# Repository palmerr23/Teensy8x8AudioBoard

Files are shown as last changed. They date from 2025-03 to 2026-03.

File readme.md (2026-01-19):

# Teensy Audio TLV320AIC3104 8x8 CODEC Board 

### Discussions have been enabled for queries or suggestions about this hardware and software. 

The Board comprises four TLV320AIC3104 stereo CODECs and a PCA9546 I2C multiplexer to allow individual CODECs to be programmed. Audio data transfer is via TDM using the standard Teensy 4.x pin allocations. Pin 22 is used for reset.

These CODECs can be programmed to offset their read/write slots to anywhere in a 256 slot TDM cycle and put the DO line in a Hi-Z state when not transmitting.

The boards are stackable to provide additional channels, by using the three address pins on the I2C muxes for board selection. While up to eight boards can be stacked, the supplied TDMA driver can accommodate two boards. 

The associated Teensy audio control software library is at https://github.com/palmerr23/control_TLV320AIC3104

If more are desired, alternate Audio libraries, such as that managed by Jonathan Oakley https://github.com/h4yn0nnym0u5e/Audio/tree/feature/multi-TDM, are suggested.

# Hardware

There are several boards in the set. 

There is further hardware information in the "8x8 and 16x16 Teensy Audio Board.docx" file.

## Main PCB

The main PCB which has the four CODECs and control logic. It features:

* 8 input channels capable of microphone  to line level  balanced (-54 dBm to +10 dBm) or unbalanced (-60 dBm to -1.5 dBm) inputs.

* 8 balanced line output channels with a maximum output level of +10dBm (+4 dbm single-ended) and capable of driving headphones or 600 ohm lines.
	
* A multiplexer to allow I2C programming of individual CODECs. 
	
* An optional -5V supply (rear of PCB) for the amplified TRS wing board option.

* The main PCB does not have decoupling capacitors on the inputs or outputs. They are on the Wing boards.

* Rev K, L and M boards are entirely interoperable. 

* Rev L & M have an additional pin on the Expansion header to assist in 32 x 32 and greater operation.

## Input and output Wing boards
Wing-boards with input or output connectors and DC coupling capacitors. Several different wing boards are offered:
* 4 x 6.5mm balanced-line TRS phone jacks. These are suitable for inputs or outputs.  2 x 3.5mm stereo headphone sockets are also provided for the output configuration.
* Combo XLR/TRS sockets for balanced or unbalanced inputs.
* Male or Female XLR sockets for balanced input or outputs.
* Female XLR sockets with phantom powering - the user needs to provide a suitable phantom power voltage source.
* An amplified 4-channel TRS output board.

# Obtaining the hardware
Several options are available for obtaining hardware. 
* Download the [Gerber Files] and have boards produced by your favorite PCB manufacturer and then mount the SMD components. The CODEC chips gave QFN SMD (no pins) packages. Only experienced constructors should consider this option.
* For the main 8x8 boards, the repository has all the necessary files to order assembled (PCBA) boards from JLCPCB. These boards are supplied with just the SMD components. The headers required must be supplied and mounted by the constructor. Carefully check component orientation using the JLCPCB utility. The AMS117 regulators, the clock signal buffers under the Teensy and the I2C bus expander are sometimes rotated.
* Input and output coupling capacitors are not implemented on the PCB, so your implementation must include them if the Wing boards are not used.
* Purchase ready-made boards from my Tindie store https://www.tindie.com/products/palmerr223/teensy-8x8-audio-board/. 

## Compatibility
Arduino 4.x with Teensyduino 1.59 or later and the supplied TDMA driver.

## CPU Load

CPU load for the basic TDM transfers is low. 

* 16 output channels driven by a single sine generator, and no inputs processed consumes 0.12% CPU on a T4.0

* Adding 2 channels of peak readings increases it to 0.35%.

* 8 channels = 0.66%

* 16 channels = 1.1%

## Power consumption
With a Teensy 4.0 and one board and all input and output channels on all four CODECs enabled the consumption is around 130 mA, mostly consumed on the 1.8V rail.

On a T4.0 with two boards and everything enabled, consumption rises to around 220 mA.

These figures are without any significant load on the outputs. Current draw will increase with low impedance loads.

Chip data (p12) indicates 4.3 + 6.7 = 11 mA per stereo (input + output) channel pair (i.e. 88 mA for 8x8).

## Open Source Hardware
These designs are  certified Open Source Hardware

https://certification.oshwa.org/list.html

ID: AU000022

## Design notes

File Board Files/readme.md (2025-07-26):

## PCBA
When ordering assembled boards, carefully check parts orientation.

Particularly, the two AMS 1117 regulators, the ISC bus expander and the TDM clock buffer chips under the Teensy have a tendency to be rotated. 

## Connector templates
TRS Board - 1/4" TRS connector base height varies between manufacturers.

XLR & Combo mounting hole position and central cutout diameter varies between manufacturers.

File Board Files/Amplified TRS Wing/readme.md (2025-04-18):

# 4 output amplified TRS Wing Board for balanced or unbalanced outputs

This board requires +/-5V supplies (via the IDC cable).

It has a gain of 3, resulting in a maximum output level of 13.691k p-p (4.8V RMS) in balanced mode or 6.8V p-p (2.4V RMS) in single-ended mode

BOM file has indicative parts only.

*CPL files are not supplied as PCBA placement and parts have not been verified*

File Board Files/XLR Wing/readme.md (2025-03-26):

# Quad XLR input or output board for balanced or unbalanced signals

Male or Female XLR sockets. 

Male sockets (output) are mounted on the *underside* of the board to ensure correct signal phase.

Only one sockect of each type is shown for clarity.

BOM is indicative of parts required. It contains both Input and Output connectors - only one set is required.

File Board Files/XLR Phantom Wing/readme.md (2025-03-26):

# Quad XLR Phantom powered input board for balancedmicrophones

Female  XLR sockets. 

Imag shows only one sockect is shown for clarity.

BOM file is indicative of parts required in addition to the PCB.

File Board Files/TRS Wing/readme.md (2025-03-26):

# Quad 6.5mm balanced-line TRS phone jacks. 

These are suitable for inputs or outputs.  

2 x 3.5mm stereo headphone sockets are also provided for the *output* configuration.

Decoupling capacitors have different values for inputs (high-impedance) and outputs (low impedance) to ensure adequate bass response.

BOM file is indicative.

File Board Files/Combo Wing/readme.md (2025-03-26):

# 4 input Combo XLR/TRS Wing Board for balanced or unbalanced inputs

Only one Combo XLR socket is shown for clarity.

BOM file has indicative parts only.

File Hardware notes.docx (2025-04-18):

# 8x8 (16x16) Teensy Audio Board Technical Notes

V1.0 March 2025

These notes should be read as an adjunct to schematics and datasheets. They are indicative of design choices but do not guarantee functionality or performance.

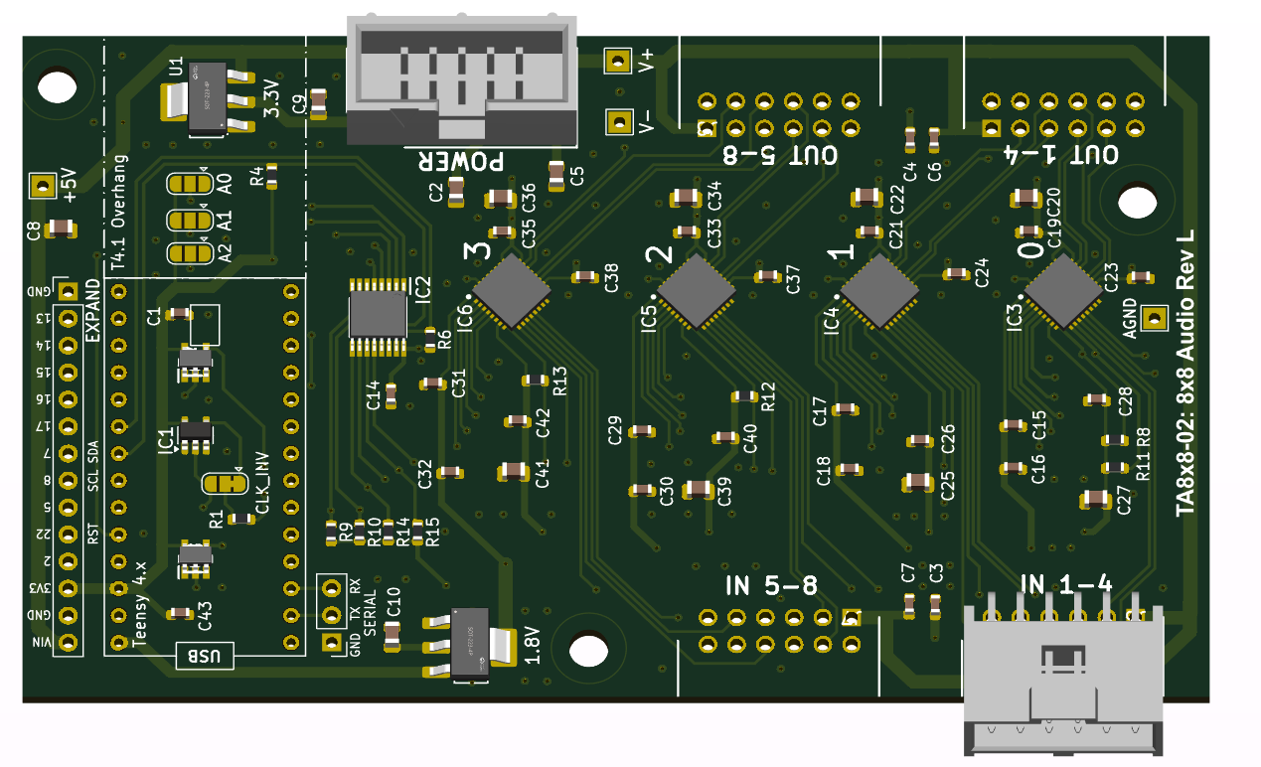
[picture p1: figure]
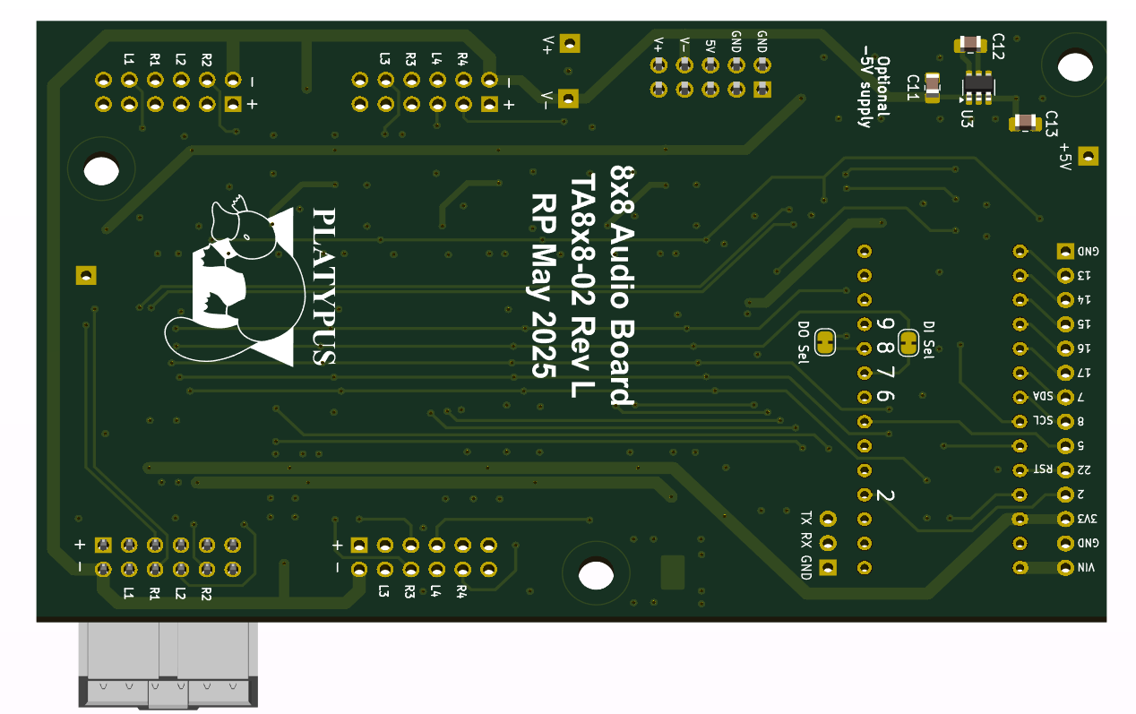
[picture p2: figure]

# Features

- 8x8 input and output channels
  - No input or output decoupling capacitors provided on main PCB.
    - Wing boards allow flexible mounting options for input and output connectors.
    - Wing boards have decoupling capacitors.
  - TLV320AIC3104 CODECs
    - TDM or I2S protocol
    - 16-, 24- or 32-bit samples
    - 44.1 or 48 kHz and multiples from 8 kHz to 96 kHz.
    - PLL capable when MCLK is absent.
- Two boards stackable (16x16) with standard Teensy TDM driver.
- Up to eight boards possible with advanced TDM drivers.
- Inputs
  - Balanced or single-ended.
  - Single-ended levels from 25 mVRMS (-60 dBm) to 0.71 VRMS (-1.5 dBm) using inbuilt PGAs.
  - Balanced levels from 50 mVRMS (-54 dBm) to 1.42 VRMS. (+10 dBm)
  - CODEC has inbuilt anti-aliasing filters on inputs and outputs.
- Outputs
  - 0.71 VRMS (2V p-p, +4 dBm) single ended or 1.42 VRMS (8V p-p, +10 dBm) differential.
  - Able to drive 16 Ω loads directly (30mW).
  - Amplified TRS wing board has x3 gain and can drive 600 Ω loads, but not low-impedance headphones.
- UART 1 is made available on a 3-pin header.
- Most unused pins are connected to a 14-pin expansion header, along with 3V, 3.3V power and the soft reset pin (22).
- A variety of input and output connector Wing boards
  - Designs are provided for 4-channel boards connected by 12-pin IDC cables.
  - All wing boards include electrolytic decoupling capacitors and anti-pop resistors.
    - ¼” TRS for input and output. Two 1/8” stereo headphone sockets are provided for the output configuration.
    - ¼” TRS amplified output. 2.4 VRMS (6.8V p-p) single ended or 4.8 VRMS (13.6V p-p) differential.
    - XLR input and output connectors.
    - Phantom powered XLR input.
    - Combo XLR input connectors.

# Specifications

Item | Measure
Output N+D (@ 90%) | 20-20kHz -92dB (differential)
Output Distortion (@ 90%) | 20-20kHz -93db 2nd Harmonic -98dB 3rd harmonic -95dB
Input N+D (Line: PGA gain = 0dB) | 20-20kHz -96dB (differential) THD (20-20k) 0.015%
Input N+D (Mic: PGA gain = 59 dB) | 20-20kHz -68dB (differential) THD (20-20k) 0.03%

### Input channel Noise and Distortion

Measured with REW @ 937 Hz at -2dB FSD.

Results show quite good performance up to 30dB gain and tapering off after that. Dynamic microphones (~50dB gain) may be better served with a low-noise preamp.

Gain | N+D (dB) | Distortion | ENOB
0dB | -97 | 0.007% | 16.0
20dB | -96 | 0.02% | 15.8
30dB | -89 | 0.02% | 14.9
40dB | -82 | 0.02% | 13.6
50dB | -75 | 0.03% | 12.0
59.5dB | -70 | 0.07% | 10.3

# Notes

- When a differential input signal is applied to a CODEC programmed as single-ended, some reflection will occur into the other channel. This appears to be because VCM is connected to the negative PGA input in single ended mode, providing a path between channels (Fig 10-13, p.36). To avoid this issue, program differential mode for all inputs for both single-ended and differential signals unless the CODECs negative input pins are not used (i.e. even pins on the input connector are left unconnected). All wing boards should be programmed with differential mode.
- When single-ended mode is used, all negative input signals should be left unconnected.

# Hardware

The hardware is compatible with Teensy 4.0 and 4.1. It may work with Teensy 3.x but this is untested.

### CODEC programming

The TLV320AIC3104 CODECs have a single I2C control address, requiring I2C multiplexing for programming multiple chips. A PCA9546A I2C mux provides access the individual TLV320AIC3104 CODEC control registers. The mux has eight addresses (0x70 – 0x77) available, selected by solder jumpers for A0-A2, providing a theoretical limit of eight boards (64 channels) attached to a single Teensy. In practice, the standard TDM driver limits the number of channels to 16.

I2C pull-up resistance is provided for each board (3.3k R8, R10) and the selected CODEC channel (6.8k) in parallel. R8/10 values are set so that the pull-up is adequate when no CODEC is selected and the current does not exceed the 3mA I2C limit when a CODEC is selected. The per-CODEC resistors are sufficient to pull-up SDA and SCL on an unselected CODEC.

If more than two boards are stacked, the value of R8/10 may need to be increased to limit the overall pull-up current to below 3mA. R8/10 = 6.8k is suggested, but not tested, for four boards.

The CODECs and mux are hard reset by a signal from GPIO 22.

### Multiple boards

The MCLK, LRCLK (WCLK) and BCLK signals have 47 Ω series resistors on each board to provide impedance matching and to damp line reflections. When more than two boards are stacked, these may need to be increased to 100 Ω per board.

0R jumpers are provided for the DI and DO signals to enable alternate Teensy pins to be used in advanced TDM modes. Series resistors may be required to condition these signals when more than two boards are stacked. They are not required for 8x8 or 16x16 operation.

### 32x32 channel operation

DI and DO need to be re-mapped on boards 3 &4. Further details are in the Commissioning Notes.

### Inputs and outputs

All CODEC inputs and outputs have on-chip filters, so further external filtering is not required.

Inputs have individually-settable PGAs with 0 – 59.5 dB gain and can be configured as differential or single-ended.

The higher-powered headphone (HP) output drivers are used as they can drive 16 Ω loads to a maximum of 30mW. Digital output level controls are not implemented as mixer and level control objects are provided in the Teensy Audio library and many objects that can output have level controls.

The line (LO) outputs are not made available at on-board connectors to save space and PCB complexity.

### Optional -5V supply

An optional LM2776 -5V voltage converter is provided on the rear of the PCB connected to the V- bus. It is intended to be powered from V+ which has been jumpered from VIN. The supply is rated at 200mA and is intended to power input or output circuitry, as required.

-5V supply components are NOT populated on the standard PCBA configuration.

### Power consumption

Each board consumes around 100mA with unloaded outputs and the ADCs and DACs of all four CODECs powered on. The majority of this is from the 1.8V rail.

3.3V consumption will rise significantly when driving low-impedance loads.

### Audio input and output connectors

Inputs and outputs are grouped in sets of four and can be configured as differential or single-ended.

The shrouded 12-pin input and output headers share pinouts to allow flexibility in the provision of appropriate audio connectors. The same connectors are used on all Wing boards and are intended to be connected via 12-way IDC cables.

The channel numbering on the inputs and outputs is different. Pin 3 is the first positive input pin, and the last positive output pin. The ground and power pins are the same on input and output connectors.

### Audio input and output connector pin-outs

Pin | Input | Output | | Pin | Input | Output
1 | V+ | V+ | | 2 | V- | V-
3 | IN1+ | OUT4+ | | 4 | IN1- | OUT4-
5 | IN2+ | OUT3+ | | 6 | IN2- | OUT3-
7 | IN3+ | OUT2+ | | 8 | IN3- | OUT2-
9 | IN4+ | OUT1+ | | 10 | IN4- | OUT1-
11 | AGND | AGND | | 12 | AGND | AGND

Connector types

Input and output (Main and Wing boards)
2 x 6 pin 2.54mm shrouded right-angle male IDC header

Right angle connectors are required if stacking several boards.

Power input
2 x 5 pin 2.54mm shrouded male IDC header

Only on the board with the Teensy

Mounting a long-pin female header on the underside of the PCB allows power pins to stack. This is only required if V+ and V- are used. The Teensy headers transfers 5V power.

Teensy and board interconnect

2 x single row 14 pin 2.54mm female header

Long pins if stacking boards.

Expansion

14 pins, including 5V, 3.3V power, ground and pin 22 reset.

Pinouts are marked on the underside of the PCB

### Expansion header

Signal | Rev K | Rev L onwards
| Pin
VIN | 14 | 15
GND | 13 | 14
3V3 | 12 | 13
2 | 11 | 12
22 RESET | 10 | 11
5 | 9 | 10
8 SCL | 8 | 9
7 SDA | 7 | 8
17 | 6 | 7
16 | 5 | 6
15 | 4 | 5
14 | 3 | 4
13 | 2 | 3
GND | 1 | 2
23 | | 1

GPIO Pins 2, 13,14,15 and 16 are uncommitted on the Expansion header.

The I2C bus and soft Reset signal are extended on the Expansion header as well as the Teensy header for boards.

An additional pin was added in Rev L to allow 32x32 operation. Other than that additional pin, the Expansion headers are compatible between revisions.

## Wing Boards

All wing boards, other than the amplified TRS board, are designed for through-hole components.

- 10uF or 100uF capacitors are 6.3 x 2.5mm, 10V or greater.
- 1uF capacitors are 5 x 2.5 mm, 10V or greater.
- Resistors are metal film, 1%, ¼ Watt.

All wing boards may be used in single-ended or differential mode. When used in single-ended mode, the coupling capacitors for the negative inputs should be omitted (see Fig 10-13 p.36) to allow these signals to float.

The 22 Ω or 47 Ω series resistors limit the output current when an active signal is grounded, for instance on TRS output boards that may single-ended cables (i.e., ring is grounded).

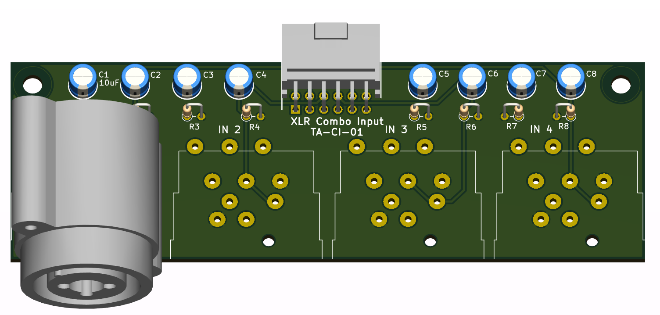
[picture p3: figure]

### Combo

This input board has four XLR combo connectors (Neutrik NCJ6FI-H, NCJ9FI-H or REAN equivalents) with decoupling capacitors and discharge resistors to reduce pops when hot-plugging.

### XLR

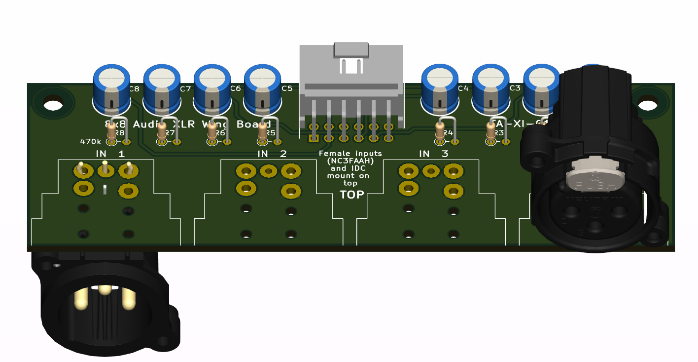
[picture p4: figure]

The XLR board has four connectors – female for inputs (Neutrik NC3FAAH or equivalent, mounted on the top of the PCB) or male for outputs (NC3MAAH or equivalent, mounted on the underside of the PCB.)

The IDC header is always mounted on the top of the board.

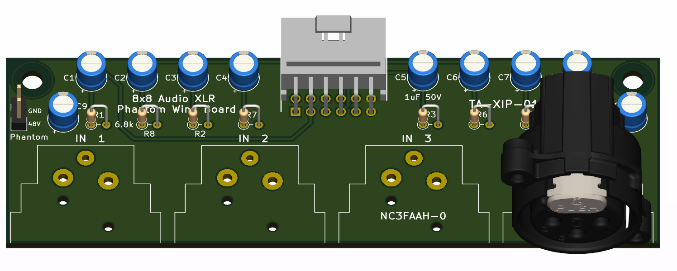
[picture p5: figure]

The board has decoupling capacitors and discharge resistors to reduce pops when hot-plugging.

### XLR Phantom input

The phantom-powered XLR input board has four female connectors (Neutrik NC3FAAH or equivalent).

A 2-pin header is provided for an external phantom power source. 6.8k phantom power resistors are specified for 48V operation. The values may be reduced for lower voltages.

The board has 50V decoupling capacitors.

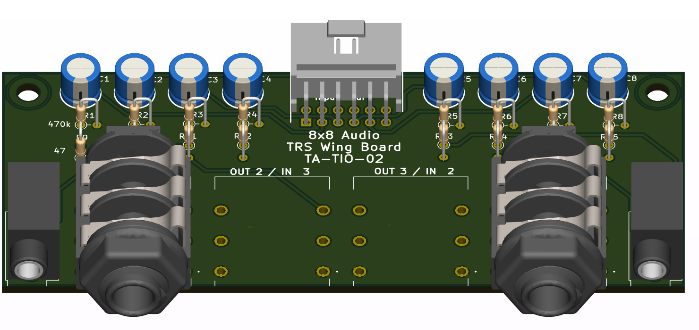
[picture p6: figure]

### TRS

The TRS board hosts four inputs or outputs.

The board has decoupling capacitors and discharge resistors to reduce pops when hot-plugging.

For output boards the 47 Ω current-limiting resistors R1-R8 are required to protect against single-ended (ring shorted to ground) cables.

For input boards the current-limiting resistors R1-R8 may be omitted and the pads linked.

The Amphenol (https://au.mouser.com/manufacturer/amphenolaudio/) ACJM-IH (https://au.mouser.com/ProductDetail/Amphenol-Audio/ACJM-IH?qs=t8VhaDIDl4v4EBLCsB4y7Q%3D%3D), Neutrik (https://au.mouser.com/manufacturer/neutrik/) NMJ4HFD3 (https://au.mouser.com/ProductDetail/Neutrik/NMJ4HFD3?qs=%252B86TLfaev2%252B4Sd%2FGmMLlUg%3D%3D) or compatible switched TRS connectors are mounted on the top of the board for both input and output applications.

Note that the channel order is different for input and output use.

If grounding of unused input channels is desired, jumpers on the underside of the PCB may be shorted. The jumpers MUST be left open for output boards.

1/8” (CUI SJ1-353xNG) headphone sockets are provided in parallel to the ¼” TRS sockets. The current-limiting resistors are bypassed. These are only required for the output configuration.

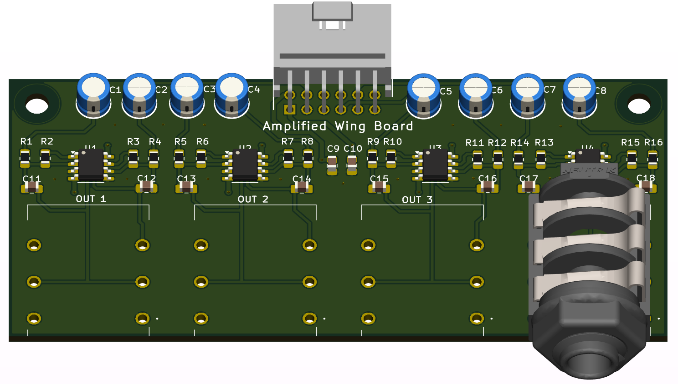
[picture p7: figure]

### Amplified TRS

Where higher-level outputs are required for professional applications the Amplified TRS board provides an additional 3x gain. The maximum levels are 2.4 VRMS (6.8V p-p) single ended and 4.8 VRMS
(13.6V p-p) differential. The board will drive 600 Ω lines to +24dBm, but is not recommended for low impedance headphones.

SMD components are used on this board to allow a more compact layout.

The LM2776 voltage inverter should be installed on the Teensy main board and Vin linked to V+. Alternately, suitable V+ and V- supplies may be provided via the Power connector.

If V+ and V- are greater than 5V, the gain may be increased to suit the op amps’ maximum output swing and drive capability. The maximum supply voltage of the op amps needs to be

# Teensy Audio Library AudioControl object

### AudioControl object

The driver for the I2C mux is incorporated into the control object and is invisible to end-user code.

The CODECs are set to select a specific 16-bit TDM slot (Reg 10) and tristate their outputs when not transmitting (Reg 8).

BCLK is inverted in hardware to avoid modifying the standard TDM driver further. This requires 1 bit to be added to the TDM slot delay.

On start-up the mux address range is scanned and 4-CODEC sets are assigned channel numbers in order of increasing mux address.

A verbose mode is available, with several levels of verbosity, for debugging.

The core functions have been tested substantially:

- 16-bit, 44.1 kHz, 8x8 and 16x16 TDM using the TDMA driver supplied.
- PGA gain using float dB or CODEC integer steps.
- 10, 20 & 50Hz high pass filters (zero offset removal).
- Single-ended and differential inputs.
- Standard “Wire” I2C at 100kHz and 400kHz.

Several other functions have been included that have only had basic checks:

- I2S operation.
- PLL to replace absent MCLK.
- 24 and 32 bit sample lengths.

Implemented and untested:

- TDMA and I2S input and output objects with sample lengths other than 16-bits.
- Sample rates other than 44.1 kHz and double rate operation.

CODEC capabilities not implemented:

- AGC
- Digital effects filtering
- Output level control (always set to 1.0). Duplicates existing Audio Library functions.
- ADC bypass functions
- Alternate mic-line inputs and MICBIAS.

## TDM driver

The standard Teensy Audio TDM driver (1.59) does not transfer odd channel audio buffers correctly. The TDMA driver supplied with the control object corrects this issue.

While the TDMA driver has an optional sample length argument, specifying 16-bits in the constructors is not required, as the default (32-bit) works with this hardware.

Jonathan Oakley’s Multi-TDM driver should also work with this hardware. https://github.com/h4yn0nnym0u5e/Audio/tree/feature/multi-TDM

(https://github.com/h4yn0nnym0u5e/Audio/tree/feature/multi-TDM)The multi-TDM driver is required if more than two boards are stacked.

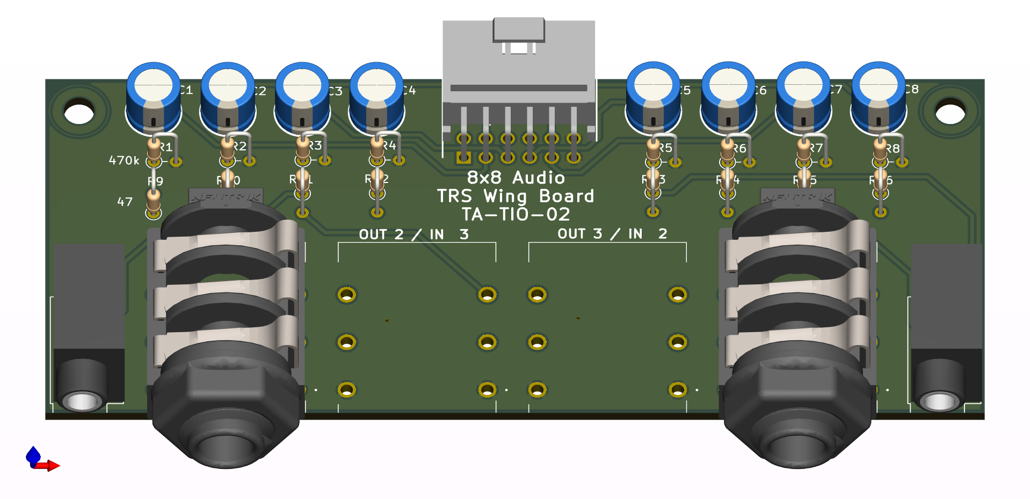
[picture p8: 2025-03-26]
Board Files/TRS Wing/Wing Board 4 TRS Mk IV.png

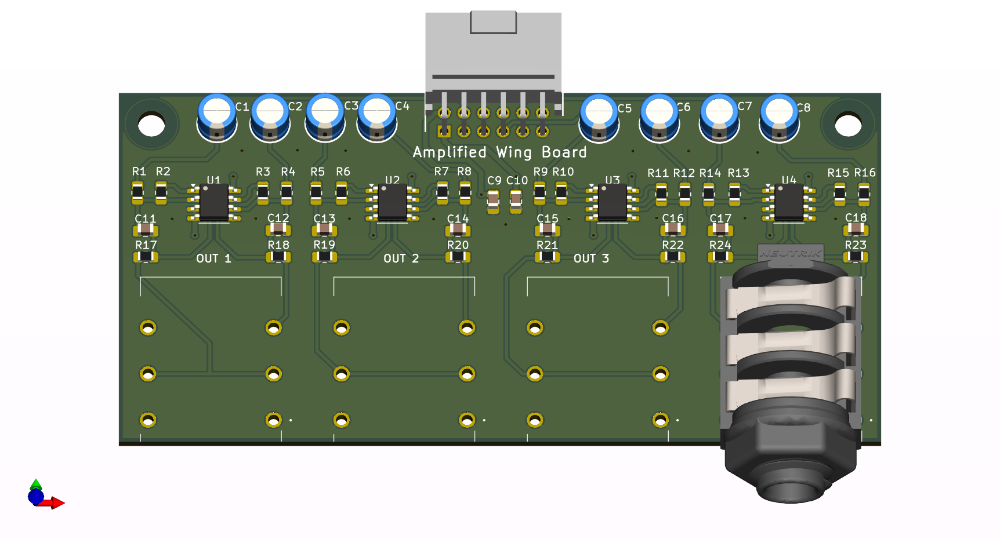
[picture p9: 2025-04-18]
Board Files/Amplified TRS Wing/Wing Board 4 TRS amp Mk II.png

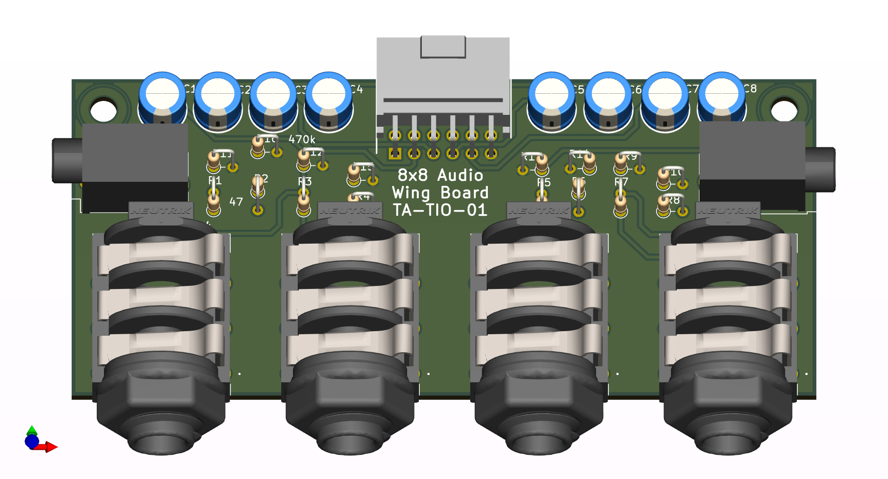
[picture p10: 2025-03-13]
Board Files/TRS Wing/Wing Board 4 TRS Mk III.png

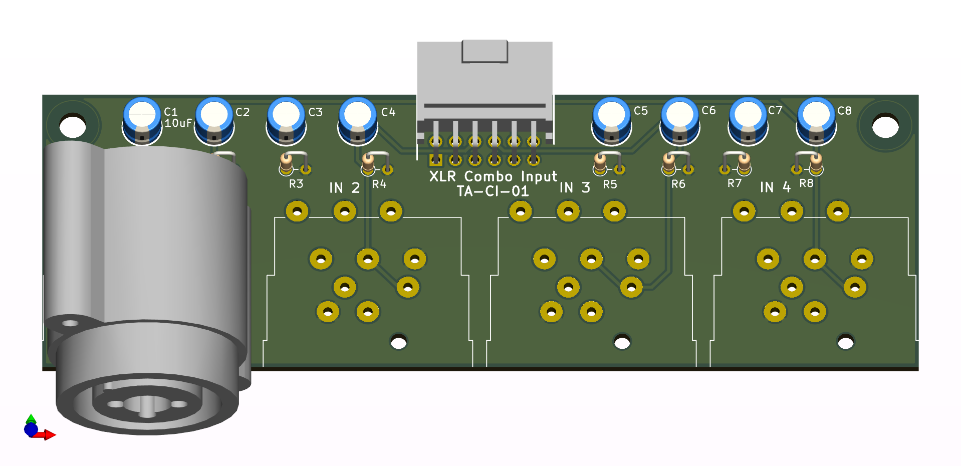
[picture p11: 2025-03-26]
Board Files/Combo Wing/Wing Board Combo.png

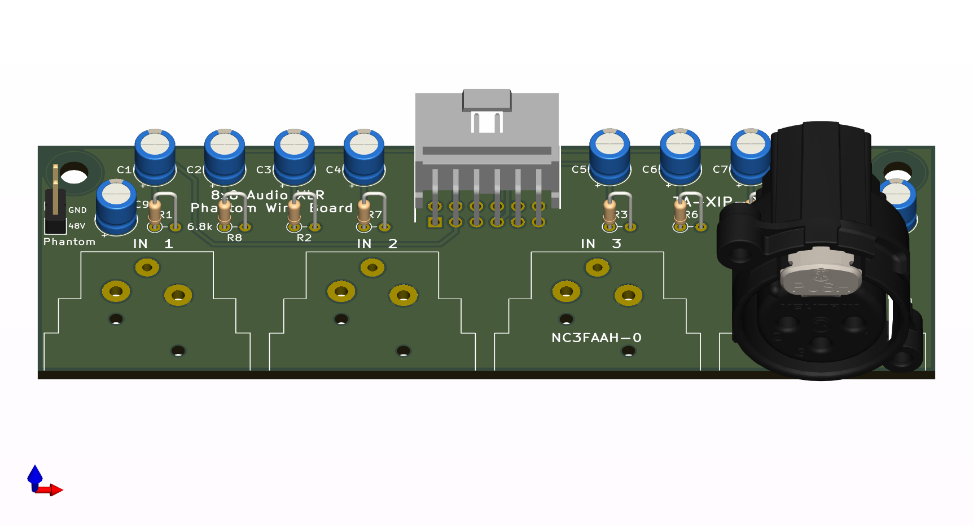
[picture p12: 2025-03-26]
Board Files/XLR Phantom Wing/Wing Board XLR Phantom.png

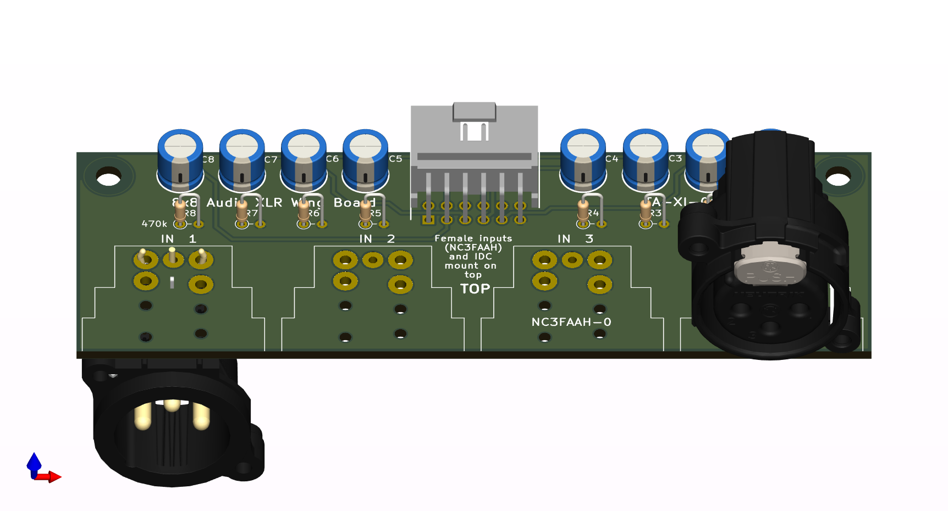
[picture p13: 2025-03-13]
Board Files/XLR Phantom Wing/Input Output XLR Wing Board.png

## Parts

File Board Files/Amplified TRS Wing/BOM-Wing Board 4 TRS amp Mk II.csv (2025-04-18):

Comment | Designator | Footprint | LCSC | Quantity
1u | C6 | CP_Radial_D5.0mm_P2.50mm |  | 1
NMJ6HFD2 | J4 | NMJ6HFD2 |  | 1
100k | R3 | R_0805_2012Metric_Pad1.20x1.40mm_HandSolder |  | 1
330p | C17 | C_0805_2012Metric_Pad1.18x1.45mm_HandSolder |  | 1
22k | R1 | R_0805_2012Metric_Pad1.20x1.40mm_HandSolder |  | 1
100k | R13 | R_0805_2012Metric_Pad1.20x1.40mm_HandSolder |  | 1
1u | C5 | CP_Radial_D5.0mm_P2.50mm |  | 1
100k | R2 | R_0805_2012Metric_Pad1.20x1.40mm_HandSolder |  | 1
330p | C15 | C_0805_2012Metric_Pad1.18x1.45mm_HandSolder |  | 1
330p | C14 | C_0805_2012Metric_Pad1.18x1.45mm_HandSolder |  | 1
100k | R15 | R_0805_2012Metric_Pad1.20x1.40mm_HandSolder |  | 1
22k | R8 | R_0805_2012Metric_Pad1.20x1.40mm_HandSolder |  | 1
330p | C16 | C_0805_2012Metric_Pad1.18x1.45mm_HandSolder |  | 1
1u | C8 | CP_Radial_D5.0mm_P2.50mm |  | 1
LM4562 | U3 | SOIC-8_3.9x4.9mm_P1.27mm |  | 1
100k | R7 | R_0805_2012Metric_Pad1.20x1.40mm_HandSolder |  | 1
Neutrik NMJ6HFD2 | J5 | NMJ6HFD2 |  | 1
LM4562 | U4 | SOIC-8_3.9x4.9mm_P1.27mm |  | 1
10u | C10 | C_0805_2012Metric_Pad1.18x1.45mm_HandSolder |  | 1
22k | R16 | R_0805_2012Metric_Pad1.20x1.40mm_HandSolder |  | 1
100k | R6 | R_0805_2012Metric_Pad1.20x1.40mm_HandSolder |  | 1
1u | C4 | CP_Radial_D5.0mm_P2.50mm |  | 1
1u | C3 | CP_Radial_D5.0mm_P2.50mm |  | 1
22k | R5 | R_0805_2012Metric_Pad1.20x1.40mm_HandSolder |  | 1
330p | C11 | C_0805_2012Metric_Pad1.18x1.45mm_HandSolder |  | 1
100k | R11 | R_0805_2012Metric_Pad1.20x1.40mm_HandSolder |  | 1
NMJ6HFD2 | J3 | NMJ6HFD2 |  | 1
INPUTS | J1 | SHDRRA12W65P254_2X6_1758X1090X1005P |  | 1
1u | C7 | CP_Radial_D5.0mm_P2.50mm |  | 1
10u | C9 | C_0805_2012Metric_Pad1.18x1.45mm_HandSolder |  | 1
330p | C18 | C_0805_2012Metric_Pad1.18x1.45mm_HandSolder |  | 1
22k | R14 | R_0805_2012Metric_Pad1.20x1.40mm_HandSolder |  | 1
330p | C12 | C_0805_2012Metric_Pad1.18x1.45mm_HandSolder |  | 1
NMJ6HFD2 | J2 | NMJ6HFD2 |  | 1
22k | R12 | R_0805_2012Metric_Pad1.20x1.40mm_HandSolder |  | 1
LM4562 | U2 | SOIC-8_3.9x4.9mm_P1.27mm |  | 1
LM4562 | U1 | SOIC-8_3.9x4.9mm_P1.27mm |  | 1
330p | C13 | C_0805_2012Metric_Pad1.18x1.45mm_HandSolder |  | 1
100k | R10 | R_0805_2012Metric_Pad1.20x1.40mm_HandSolder |  | 1
22k | R9 | R_0805_2012Metric_Pad1.20x1.40mm_HandSolder |  | 1
22k | R4 | R_0805_2012Metric_Pad1.20x1.40mm_HandSolder |  | 1
1u | C2 | CP_Radial_D5.0mm_P2.50mm |  | 1
1u | C1 | CP_Radial_D5.0mm_P2.50mm |  | 1
22 | R24 | R_0805_2012Metric_Pad1.20x1.40mm_HandSolder |  | 1
22 | R23 | R_0805_2012Metric_Pad1.20x1.40mm_HandSolder |  | 1
22 | R22 | R_0805_2012Metric_Pad1.20x1.40mm_HandSolder |  | 1
22 | R21 | R_0805_2012Metric_Pad1.20x1.40mm_HandSolder |  | 1
22 | R20 | R_0805_2012Metric_Pad1.20x1.40mm_HandSolder |  | 1
22 | R19 | R_0805_2012Metric_Pad1.20x1.40mm_HandSolder |  | 1
22 | R18 | R_0805_2012Metric_Pad1.20x1.40mm_HandSolder |  | 1
22 | R17 | R_0805_2012Metric_Pad1.20x1.40mm_HandSolder |  | 1

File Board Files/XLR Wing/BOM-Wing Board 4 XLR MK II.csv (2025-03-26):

Comment | Designator | Footprint | LCSC | Quantity
470k | R6 | R_Axial_DIN0204_L3.6mm_D1.6mm_P2.54mm_Vertical |  | 1
NC3FAAH-0 | J5 | Jack_XLR_Neutrik_NC3FAAH-0_Horizontal |  | 1
470k | R8 | R_Axial_DIN0204_L3.6mm_D1.6mm_P2.54mm_Vertical |  | 1
470k | R5 | R_Axial_DIN0204_L3.6mm_D1.6mm_P2.54mm_Vertical |  | 1
10uF | C8 | CP_Radial_D6.3mm_P2.50mm |  | 1
10uF | C5 | CP_Radial_D6.3mm_P2.50mm |  | 1
10uF | C7 | CP_Radial_D6.3mm_P2.50mm |  | 1
470k | R2 | R_Axial_DIN0204_L3.6mm_D1.6mm_P2.54mm_Vertical |  | 1
10uF | C3 | CP_Radial_D6.3mm_P2.50mm |  | 1
10uF | C6 | CP_Radial_D6.3mm_P2.50mm |  | 1
NC3FAAH-0 | J2 | Jack_XLR_Neutrik_NC3FAAH-0_Horizontal |  | 1
NC3FAAH-0 | J4 | Jack_XLR_Neutrik_NC3FAAH-0_Horizontal |  | 1
INPUTS | J1 | SHDRRA12W65P254_2X6_1758X1090X1005P |  | 1
470k | R4 | R_Axial_DIN0204_L3.6mm_D1.6mm_P2.54mm_Vertical |  | 1
470k | R1 | R_Axial_DIN0204_L3.6mm_D1.6mm_P2.54mm_Vertical |  | 1
10uF | C2 | CP_Radial_D6.3mm_P2.50mm |  | 1
10uF | C4 | CP_Radial_D6.3mm_P2.50mm |  | 1
470k | R7 | R_Axial_DIN0204_L3.6mm_D1.6mm_P2.54mm_Vertical |  | 1
470k | R3 | R_Axial_DIN0204_L3.6mm_D1.6mm_P2.54mm_Vertical |  | 1
10uF | C1 | CP_Radial_D6.3mm_P2.50mm |  | 1
NC3FAAH-0 | J3 | Jack_XLR_Neutrik_NC3FAAH-0_Horizontal |  | 1
NC3MAAH-1 | J9 | Jack_XLR_Neutrik_NC3MAAH-1_Horizontal |  | 1
NC3MAAH-1 | J6 | Jack_XLR_Neutrik_NC3MAAH-1_Horizontal |  | 1
NC3MAAH-1 | J8 | Jack_XLR_Neutrik_NC3MAAH-1_Horizontal |  | 1
NC3MAAH-1 | J7 | Jack_XLR_Neutrik_NC3MAAH-1_Horizontal |  | 1

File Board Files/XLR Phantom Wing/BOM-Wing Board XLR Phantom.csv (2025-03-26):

Comment | Designator | Footprint | LCSC | Quantity
1uF | C10 | CP_Radial_D5.0mm_P2.00mm |  | 1
1uF | C9 | CP_Radial_D5.0mm_P2.00mm |  | 1
Phantom | J5 | PinHeader_1x02_P2.54mm_Vertical |  | 1
1uF | C8 | CP_Radial_D5.0mm_P2.00mm |  | 1
1uF | C7 | CP_Radial_D5.0mm_P2.00mm |  | 1
1uF | C6 | CP_Radial_D5.0mm_P2.00mm |  | 1
1uF 50V | C5 | CP_Radial_D5.0mm_P2.00mm |  | 1
1uF | C4 | CP_Radial_D5.0mm_P2.00mm |  | 1
1uF | C3 | CP_Radial_D5.0mm_P2.00mm |  | 1
1uF | C2 | CP_Radial_D5.0mm_P2.00mm |  | 1
1uF | C1 | CP_Radial_D5.0mm_P2.00mm |  | 1
6.8k | R2 | R_Axial_DIN0204_L3.6mm_D1.6mm_P2.54mm_Vertical |  | 1
NC3FAAH-0 | J6 | Jack_XLR_Neutrik_NC3FAAH-0_Horizontal |  | 1
6.8k | R1 | R_Axial_DIN0204_L3.6mm_D1.6mm_P2.54mm_Vertical |  | 1
6.8k | R7 | R_Axial_DIN0204_L3.6mm_D1.6mm_P2.54mm_Vertical |  | 1
6.8k | R4 | R_Axial_DIN0204_L3.6mm_D1.6mm_P2.54mm_Vertical |  | 1
NC3FAAH-0 | J1 | Jack_XLR_Neutrik_NC3FAAH-0_Horizontal |  | 1
NC3FAAH-0 | J4 | Jack_XLR_Neutrik_NC3FAAH-0_Horizontal |  | 1
INPUTS | J3 | SHDRRA12W65P254_2X6_1758X1090X1005P |  | 1
6.8k | R3 | R_Axial_DIN0204_L3.6mm_D1.6mm_P2.54mm_Vertical |  | 1
6.8k | R5 | R_Axial_DIN0204_L3.6mm_D1.6mm_P2.54mm_Vertical |  | 1
6.8k | R8 | R_Axial_DIN0204_L3.6mm_D1.6mm_P2.54mm_Vertical |  | 1
6.8k | R6 | R_Axial_DIN0204_L3.6mm_D1.6mm_P2.54mm_Vertical |  | 1
NC3FAAH-0 | J2 | Jack_XLR_Neutrik_NC3FAAH-0_Horizontal |  | 1

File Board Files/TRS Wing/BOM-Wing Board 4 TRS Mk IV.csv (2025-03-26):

Comment | Designator | Footprint | LCSC | Quantity
10uF | C6 | CP_Radial_D6.3mm_P2.50mm |  | 1
NMJ6HFD2 | J4 | NMJ6HFD2 |  | 1
47 | R14 | R_Axial_DIN0204_L3.6mm_D1.6mm_P2.54mm_Vertical |  | 1
470k | R4 | R_Axial_DIN0204_L3.6mm_D1.6mm_P2.54mm_Vertical |  | 1
47 | R15 | R_Axial_DIN0204_L3.6mm_D1.6mm_P2.54mm_Vertical |  | 1
10uF | C5 | CP_Radial_D6.3mm_P2.50mm |  | 1
NMJ6HFD2 | J5 | NMJ6HFD2 |  | 1
47 | R9 | R_Axial_DIN0204_L3.6mm_D1.6mm_P2.54mm_Vertical |  | 1
10uF | C7 | CP_Radial_D6.3mm_P2.50mm |  | 1
CUI SJ1-353xNG | J2 | Jack_3.5mm_CUI_SJ1-3535NG_Horizontal_CircularHoles |  | 1
470k | R8 | R_Axial_DIN0204_L3.6mm_D1.6mm_P2.54mm_Vertical |  | 1
470k | R3 | R_Axial_DIN0204_L3.6mm_D1.6mm_P2.54mm_Vertical |  | 1
47 | R13 | R_Axial_DIN0204_L3.6mm_D1.6mm_P2.54mm_Vertical |  | 1
10uF | C4 | CP_Radial_D6.3mm_P2.50mm |  | 1
10uF | C3 | CP_Radial_D6.3mm_P2.50mm |  | 1
470k | R1 | R_Axial_DIN0204_L3.6mm_D1.6mm_P2.54mm_Vertical |  | 1
47 | R11 | R_Axial_DIN0204_L3.6mm_D1.6mm_P2.54mm_Vertical |  | 1
Neutrik NMJ6HFD2 | J6 | NMJ6HFD2 |  | 1
INPUTS | J1 | SHDRRA12W65P254_2X6_1758X1090X1005P |  | 1
470k | R5 | R_Axial_DIN0204_L3.6mm_D1.6mm_P2.54mm_Vertical |  | 1
10uF | C8 | CP_Radial_D6.3mm_P2.50mm |  | 1
470k | R6 | R_Axial_DIN0204_L3.6mm_D1.6mm_P2.54mm_Vertical |  | 1
NMJ6HFD2 | J3 | NMJ6HFD2 |  | 1
CUI SJ1-353xNG | J7 | Jack_3.5mm_CUI_SJ1-3535NG_Horizontal_CircularHoles |  | 1
47 | R10 | R_Axial_DIN0204_L3.6mm_D1.6mm_P2.54mm_Vertical |  | 1
470k | R2 | R_Axial_DIN0204_L3.6mm_D1.6mm_P2.54mm_Vertical |  | 1
47 | R12 | R_Axial_DIN0204_L3.6mm_D1.6mm_P2.54mm_Vertical |  | 1
10uF | C2 | CP_Radial_D6.3mm_P2.50mm |  | 1
10uF | C1 | CP_Radial_D6.3mm_P2.50mm |  | 1
470k | R7 | R_Axial_DIN0204_L3.6mm_D1.6mm_P2.54mm_Vertical |  | 1
47 | R16 | R_Axial_DIN0204_L3.6mm_D1.6mm_P2.54mm_Vertical |  | 1
GND | JP7 | SolderJumper-2_P1.3mm_Open_RoundedPad1.0x1.5mm |  | 1
GND | JP4 | SolderJumper-2_P1.3mm_Open_RoundedPad1.0x1.5mm |  | 1
GND | JP6 | SolderJumper-2_P1.3mm_Open_RoundedPad1.0x1.5mm |  | 1
GND | JP8 | SolderJumper-2_P1.3mm_Open_RoundedPad1.0x1.5mm |  | 1
GND | JP2 | SolderJumper-2_P1.3mm_Open_RoundedPad1.0x1.5mm |  | 1
GND | JP1 | SolderJumper-2_P1.3mm_Open_RoundedPad1.0x1.5mm |  | 1
GND | JP3 | SolderJumper-2_P1.3mm_Open_RoundedPad1.0x1.5mm |  | 1
GND | JP5 | SolderJumper-2_P1.3mm_Open_RoundedPad1.0x1.5mm |  | 1

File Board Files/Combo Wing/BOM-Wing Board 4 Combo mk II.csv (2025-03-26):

Comment | Designator | Footprint | LCSC | Quantity
470k | R5 | R_Axial_DIN0204_L3.6mm_D1.6mm_P2.54mm_Vertical |  | 1
470k | R4 | R_Axial_DIN0204_L3.6mm_D1.6mm_P2.54mm_Vertical |  | 1
NCJ9FI-H | J5 | Jack_XLR-6.35mm_Neutrik_NCJ9FI-H_Horizontal |  | 1
10uF | C4 | CP_Radial_D5.0mm_P2.00mm |  | 1
470k | R2 | R_Axial_DIN0204_L3.6mm_D1.6mm_P2.54mm_Vertical |  | 1
NCJ9FI-H | J3 | Jack_XLR-6.35mm_Neutrik_NCJ9FI-H_Horizontal |  | 1
10uF | C8 | CP_Radial_D5.0mm_P2.00mm |  | 1
470k | R8 | R_Axial_DIN0204_L3.6mm_D1.6mm_P2.54mm_Vertical |  | 1
INPUTS | J1 | SHDRRA12W65P254_2X6_1758X1090X1005P |  | 1
470k | R7 | R_Axial_DIN0204_L3.6mm_D1.6mm_P2.54mm_Vertical |  | 1
470k | R1 | R_Axial_DIN0204_L3.6mm_D1.6mm_P2.54mm_Vertical |  | 1
NCJ9FI-H | J4 | Jack_XLR-6.35mm_Neutrik_NCJ9FI-H_Horizontal |  | 1
10uF | C3 | CP_Radial_D5.0mm_P2.00mm |  | 1
NCJ9FI-H | J2 | Jack_XLR-6.35mm_Neutrik_NCJ9FI-H_Horizontal |  | 1
10uF | C2 | CP_Radial_D5.0mm_P2.00mm |  | 1
10uF | C7 | CP_Radial_D5.0mm_P2.00mm |  | 1
470k | R3 | R_Axial_DIN0204_L3.6mm_D1.6mm_P2.54mm_Vertical |  | 1
470k | R6 | R_Axial_DIN0204_L3.6mm_D1.6mm_P2.54mm_Vertical |  | 1
10uF | C6 | CP_Radial_D5.0mm_P2.00mm |  | 1
10uF | C5 | CP_Radial_D5.0mm_P2.00mm |  | 1
10uF | C1 | CP_Radial_D5.0mm_P2.00mm |  | 1

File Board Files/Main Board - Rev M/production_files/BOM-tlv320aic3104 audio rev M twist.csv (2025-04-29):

Comment | Designator | Footprint | LCSC | Quantity
100n | C14,C15,C17,C19,C21,C26,C28,C29,C31,C33,C35,C40,C42 | C_0603 | C14663 | 13
1u | C1,C16,C18,C23,C24,C3,C30,C32,C37,C38,C4,C43,C6,C7 | C_0603 | C15849 | 14
10u | C10,C2,C20,C22,C25,C27,C34,C36,C39,C41,C5,C8,C9 | C_0805 | C15850 | 13
TLV320AIC3104IRHBR | IC3,IC4,IC5,IC6 | QFN50P500X500X100-33N-D | C181753 | 4
3k3 | R4,R6 | R_0603 | C22978 | 2
47 | R1,R2,R3 | R_0603 | C23182 | 3
6k8 | R10,R11,R12,R13,R14,R15,R8,R9 | R_0603 | C23212 | 8
SN74LVC1G125DBVR | IC7,IC8 | SOT95P280X145-5N | C23654 | 2
PCA9546APWR | IC2 | SOP65P640X120-16N | C400705 | 1
AMS1117-1.8 | U2 | SOT-223-3_L6.5-W3.4-P2.30-LS7.0-BR | C6185 | 1
AMS1117-3.3 | U1 | SOT-223-3_L6.5-W3.4-P2.30-LS7.0-BR | C6186 | 1
SN74LVC1G04DBVR-MS | IC1 | SOT-23-5 | C7434171 | 1

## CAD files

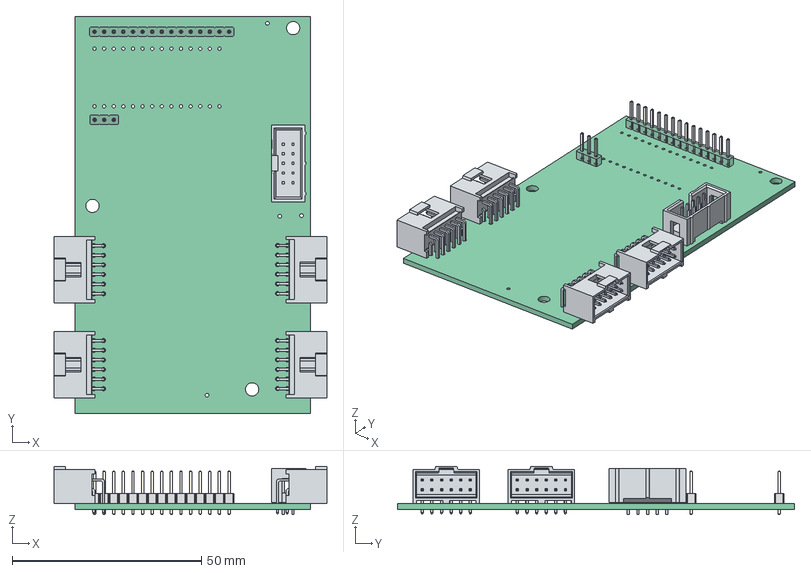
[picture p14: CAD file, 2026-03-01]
Board Files/Main Board - Rev M/tlv320aic3104 audio rev M twist.step
72.1 x 104.9 x 12.8 mm
Pcb_9f5c
J1_PinHeader_1x03_P254mm_Vertical_641d8b180097
POWER1_C-1761681-3_bb0363d08ec1
J4_901303112_a920b62f8c90 x 4
J2_PinHeader_1x15_P254mm_Vertical_3d8c39330363

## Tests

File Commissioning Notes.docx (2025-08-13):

# 8x8 Teensy Audio Board Commissioning Notes

V1.0 April 2025

These notes explain matters relevant to building and commissioning the main CODEC board and Wing boards.

There is relevant information in the Technical Notes that is not duplicated here.

Project schematics and component datasheets may also be valuable resources. Page references are to the TVL320AIC3104 datasheet.

# PCBA boards from JLCPCB

For the main 8x8 boards, the repository has all the necessary files to order assembled (PCBA) boards from JLCPCB. These boards are supplied with just the SMD components.

The headers required must be supplied and mounted by the constructor.

Carefully check component orientation using the JLCPCB utility. The AMS117 regulators, the clock signal buffers under the Teensy and the I2C bus expander are sometimes rotated.

# Stacking

12x3mm spacers should be used for stacking boards. The ones with 6mm male screw threads provide more secure mounting than those with 3mm threads.

Constructors should ensure that the 5V power supply is adequate.

If more than two boards are stacked or significant power is drawn on the V+ and V- lines (when connected to VIN and the on-board -5V supply), the POWER header should be used rather than the USB connector on the Teensy, as the current draw is likely to approach or exceed 0.5 amps.

Where the POWER connector is used, care should be taken to ensure correct orientation of the IDC cable (see Connectors, below).

Where the USB connector is used for an audio connection and +5V power is being supplied through the POWER connector, the instructions on the Teensy website for non-USB powering should be followed - https://www.pjrc.com/store/teensy40.html

## On-board jumpers

To function correctly each board in a stack must be jumpered to a different address.

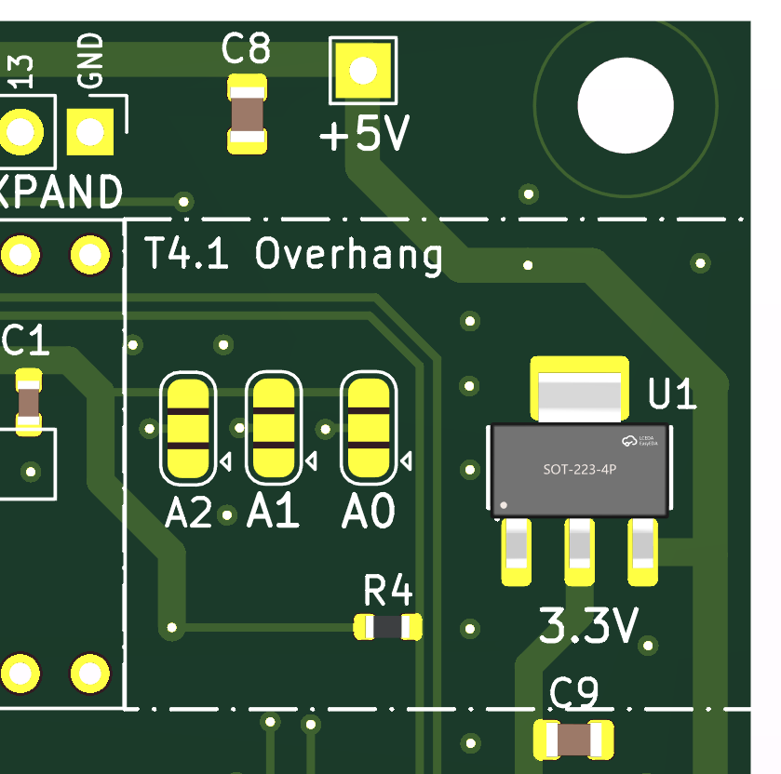
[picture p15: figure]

This is accomplished by bridging the appropriate pads on the A0 A1 and A2 jumpers near the end of the Teensy headers. The pair of pads near the Ax legends is 0 and the opposite pair is 1.

For the first board, the jumpers are:

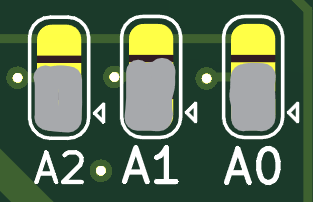
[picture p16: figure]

For the second board:

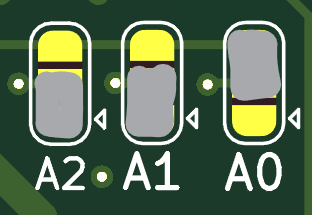
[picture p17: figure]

The input and output channel numbers are assigned using these addresses. The physical stacking order does not matter.

## 32x32 mode (Rev L or later ONLY)

Jonathan Oakley’s Multi-TDM driver is required if more than two boards are stacked. https://github.com/h4yn0nnym0u5e/Audio/tree/feature/multi-TDM

(https://github.com/h4yn0nnym0u5e/Audio/tree/feature/multi-TDM)On the main PCB (with the Teensy) GPIO pin 23 needs to be connected to the expansion header in 32x32 mode using a fly-lead.

The pin is at the end near the SD card holder on a T4.1 and on the rear of a T4.0

The DI and DO jumpers on the rear of boards 3 & 4 in the stack should be cut and connected:
to DI <–> Teensy GPIO 6 and DO <–> Teensy GPIO 23.

Board | DO GPIO | DI GPIO
1 & 2 | 8 | 7
3 & 4 | 6 | 23

# Input Configuration

When a differential input signal is applied to a CODEC programmed as single-ended, some reflection will occur into the other channel. This appears to be because VCM is connected to the negative PGA input in single ended mode, providing a path between channels (Fig 10-13, p.36).

To avoid this issue, program differential mode for all inputs for both single-ended and differential signals unless the CODECs negative input pins are not used (i.e. even pins on the input connector are left unconnected).

All wing boards should be programmed with differential mode.

When single-ended mode is used, all negative input signals should be left unconnected.

# Connectors

### Main Board

The four 6x2 right-angle IDC input and output connectors mount on the top of the PCB.

The 14-pin Teensy headers are supplied with long pins to enable stacking multiple boards. If stacking is not required, the pins may be trimmed after soldering.

The 5x2 power connector is a long-pin female type, which mounts on the REAR of the PCB to facilitate stacking. To protect against incorrect orientation of the IDC power cable the outer shell of a shrouded 5x2 male connector can be slipped over the pins. Some countersinking of the pin holes on the underside of the shell may be required for the shroud to fit snugly to the PCB.

For 8x8 configurations the POWER connector can be substituted with a 5x2 shrouded male IDC connector.

The EXPANSION header does not need to be connected between CODEC boards.

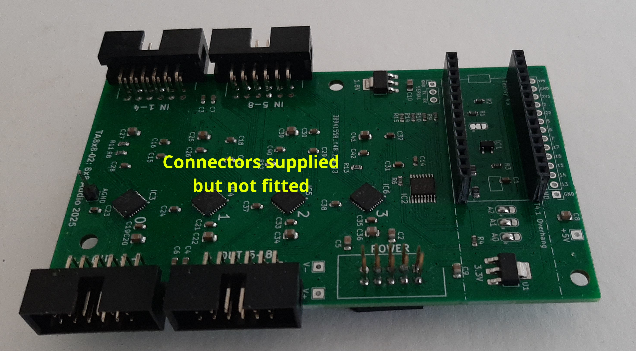
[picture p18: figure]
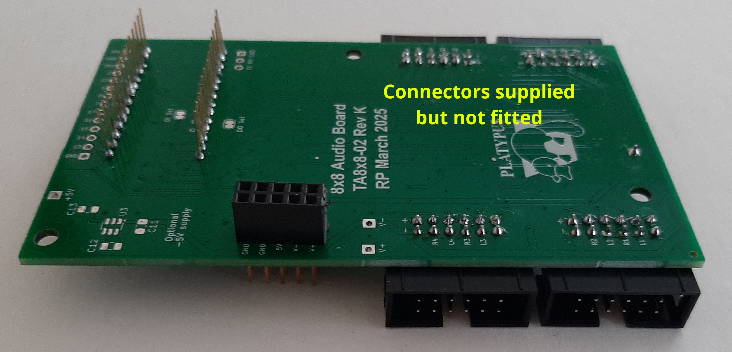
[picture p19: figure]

### Wing Boards

The IDC connector mounts on the top of the PCB for all Wing boards.

On the XLR Input/Output board:

- Input (female) connectors mount on the TOP of the board.
- Output (male) connectors mount on the BOTTOM of the board

On the TRS board:

- The 1/8” headphone jacks are only required for the output configuration.

The channel numbering on the 6x2 IDC connector for inputs and outputs is different. Pin 3 is the first positive input pin, and the last positive output pin. The ground and power pins are the same on input and output connectors.

### Input and Output Connectors (2 x6)

Pin | Input | Output | | Pin | Input | Output
1 | V+ | V+ | | 2 | V- | V-
3 | IN1+ | OUT4+ | | 4 | IN1- | OUT4-
5 | IN2+ | OUT3+ | | 6 | IN2- | OUT3-
7 | IN3+ | OUT2+ | | 8 | IN3- | OUT2-
9 | IN4+ | OUT1+ | | 10 | IN4- | OUT1-
11 | AGND | AGND | | 12 | AGND | AGND

### Power Connector (2x5)

Pin | Signal | | Pin | Signal
1 | GND | | 2 | GND
3 | GND | | 4 | GND
5 | VIN (+5V) | | 6 | VIN (+5V)
7 | V- (analogue) | | 8 | V-
9 | V+ (analogue | | 10 | V+

### Main Board Connector Types

Connectors

Input and output (Main and Wing boards)
2 x 6 pin 2.54mm shrouded right-angle male IDC header

Right angle connectors are required if stacking several boards.

Power input
Stacked: 2 x 5 pin 2.54mm long pin female header

Single board: 2 x 5 pin 2.54mm male shrouded IDC header

Mounting a long-pin female header on the underside of the PCB allows power pins to stack. This is only required if V+ and V- are used. The Teensy headers transfer 5V and 3.3V power.

Teensy and board interconnect

2 x single row 14 pin 2.54mm female header

Long pins if stacking boards.

Expansion

14 pins, including 5V, 3.3V power, ground and pin 22 reset.

Pinouts are marked on the underside of the PCB

The expansion header does not need to be connected between boards.

### Expansion header

Pin | Signal
14 | VIN
13 | GND
12 | 3V3
11 | 2
10 | 22 RST
9 | 5
8 | 8 SCL
7 | 7 SDA
6 | 17
5 | 16
4 | 15
3 | 14
2 | 13
1 | GND

GPIO Pins 2, 13,14,15 and 16 are uncommitted on the Expansion header.

The I2C bus and soft Reset signal are extended on the Expansion header as well as the Teensy header for boards.

## Wing Board Components

Electrolytic capacitors are polarity-sensitive. The white stripe on the capacitor matches with the white semicircle on the PCB. Resistors are not polarised.

All wing boards, other than the amplified TRS board, are designed for through-hole components.

The boards have decoupling capacitors and discharge resistors to reduce pops when hot-plugging.

1uF or 10uF electrolytic capacitors may be used for all inputs (the ADC input impedance is > 30 K ohms).

On outputs, 100uF capacitors provide better low frequency response when driving low-impedance loads such as headphones or 600 ohm balanced lines.

- 10uF or 100uF capacitors are 6.3 x 2.5mm, 10V or greater.
- 50V capacitors are required for phantom powering.
- 1uF capacitors are 5 x 2.5 mm, 10V or greater.
- Resistors are metal film, 5%, ¼ Watt.

All wing boards may be used in single-ended or differential mode. When used in single-ended mode, the coupling capacitors for the negative inputs should be omitted (see Fig 10-13 p.36) to allow these signals to float (see Input Configuration, below).

For output boards the 47 Ω current-limiting resistors R1-R8 are required to protect against single-ended (ring shorted to ground) cables.

### TRS

The TRS board hosts four inputs or outputs.

For input boards the current-limiting resistors R1-R8 may be omitted and the pads linked.

The Amphenol (https://au.mouser.com/manufacturer/amphenolaudio/) ACJM-IH (https://au.mouser.com/ProductDetail/Amphenol-Audio/ACJM-IH?qs=t8VhaDIDl4v4EBLCsB4y7Q%3D%3D), Neutrik (https://au.mouser.com/manufacturer/neutrik/) NMJ4HFD3 (https://au.mouser.com/ProductDetail/Neutrik/NMJ4HFD3?qs=%252B86TLfaev2%252B4Sd%2FGmMLlUg%3D%3D) or compatible switched TRS connectors are mounted on the top of the board for both input and output applications.

If grounding of unused input channels is desired, jumpers on the underside of the PCB may be shorted. The jumpers MUST be left open for output boards.

Note that the channel order is different for input and output use.

1/8” (CUI SJ1-353xNG) headphone sockets are provided in parallel to the ¼” TRS sockets. The current-limiting resistors are bypassed. These are only required for the output configuration.

### XLR

The XLR board has four connectors – female for inputs (Neutrik NC3FAAH or equivalent, mounted on the top of the PCB) or male for outputs (NC3MAAH or equivalent, mounted on the underside of the PCB.)

### Combo XLR

This input board has four XLR combo connectors (Neutrik NCJ6FI-H, NCJ9FI-H or REAN equivalents) with decoupling capacitors and discharge resistors to reduce pops when hot-plugging.

## Additional designs

### Amplified TRS

Where higher-level outputs are required for professional applications the Amplified TRS board provides an additional 3x gain. The maximum levels are 2.4 VRMS (6.8V p-p) single ended and 4.8 VRMS (13.6V p-p) differential. The board will drive 600 Ω lines to +8dBm, but is not recommended for low impedance headphones.

SMD components are used on this board to allow a more compact layout.

The LM2776 voltage inverter should be installed on the Teensy main board and Vin linked to V+. Alternately, suitable V+ and V- supplies may be provided via the Power connector.

If V+ and V- are greater than 5V, the gain may be increased to suit the op amps’ maximum output swing and drive capability. The maximum supply voltage of the op amps needs to be at least equal to the sum of the supply rail voltages.

### XLR Phantom input

The phantom-powered XLR input board has four female connectors (Neutrik NC3FAAH or equivalent).

A 2-pin header is provided for an external phantom power source. 6.8k phantom power resistors are specified for 48V operation. The values may be reduced for lower voltages.

The board has 50V decoupling capacitors.

# Using the Boards

## Software

The examples provided with the control_TLV320AIC3104 library demonstrate the basic requirements: of using the control_TLV320AIC3104 object to enable the CODECs and TDM transfers.

To simplify coding of multiple inputs and outputs, dynamic AudioConnections are demonstrated.

Function references are in the readme.md file provided with the library.

As of Teensyduino 1.59 the standard TDM driver does not handle samples from odd numbered channels correctly. The TDMA driver supplied with the library does. It is believed that 1.60 will correct the issues, but a release date had not been set at the time of writing.

Jonathan Oakley’s Multi-TDM driver should also work with this hardware. https://github.com/h4yn0nnym0u5e/Audio/tree/feature/multi-TDM

(https://github.com/h4yn0nnym0u5e/Audio/tree/feature/multi-TDM)The multi-TDM driver is required if more than two boards are stacked.

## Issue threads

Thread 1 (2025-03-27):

real-time multiple channel

shihweichieh2023, 2025-03-27:
Hi

Does this supports usb audio interface? so I can send multiple audio channels from my DAW in TDM in realtime?

palmerr23, 2025-03-27:
**Please use the teensy discussion forum for questions.**

Short answer. USB is separate and you can connect to it if you like. USB is 2 channels only due to Teensy USB speed. My Teensy Ethernet Audio can do multiple channels using a T4.1. Works with this board. You need to use the VBAN interface for your DAW.

palmerr23, 2025-03-27:
No I'm not interested. Thank you for the offer.

Closed 2025-03-27.

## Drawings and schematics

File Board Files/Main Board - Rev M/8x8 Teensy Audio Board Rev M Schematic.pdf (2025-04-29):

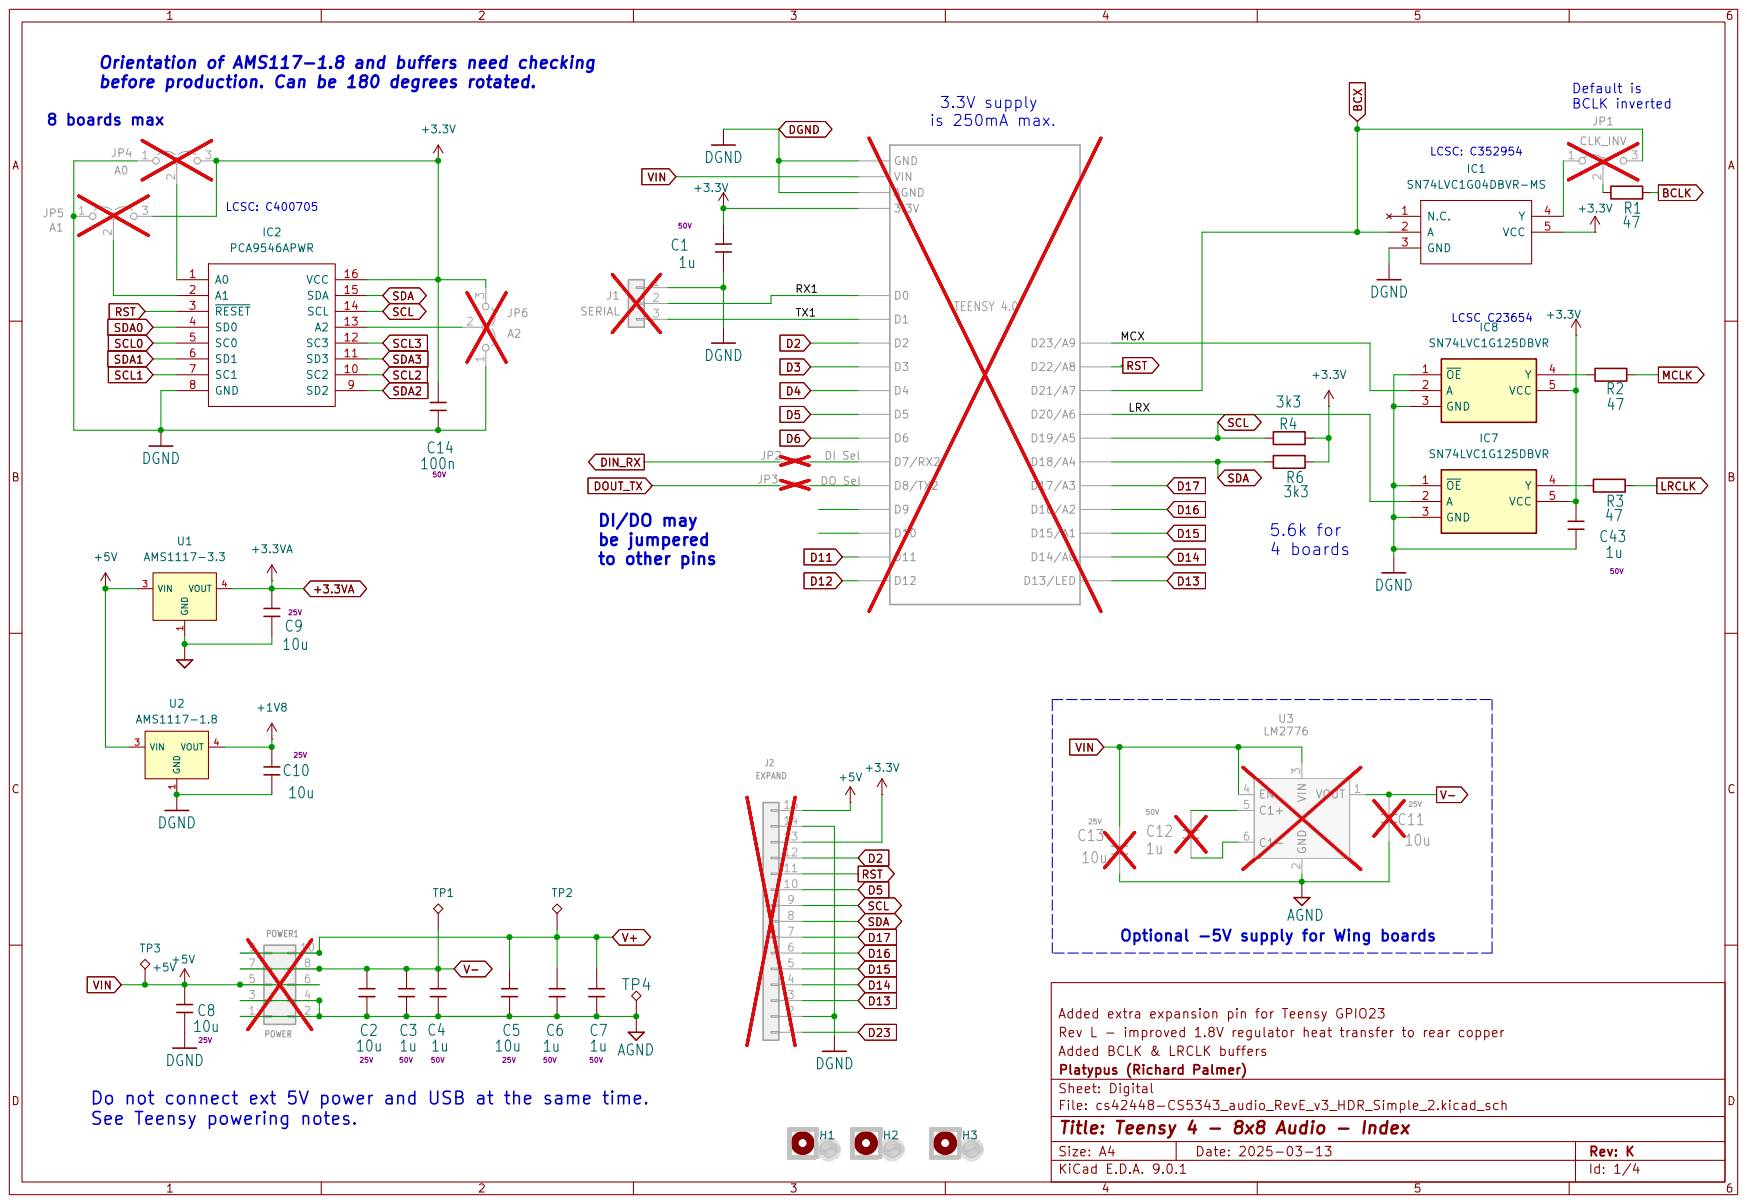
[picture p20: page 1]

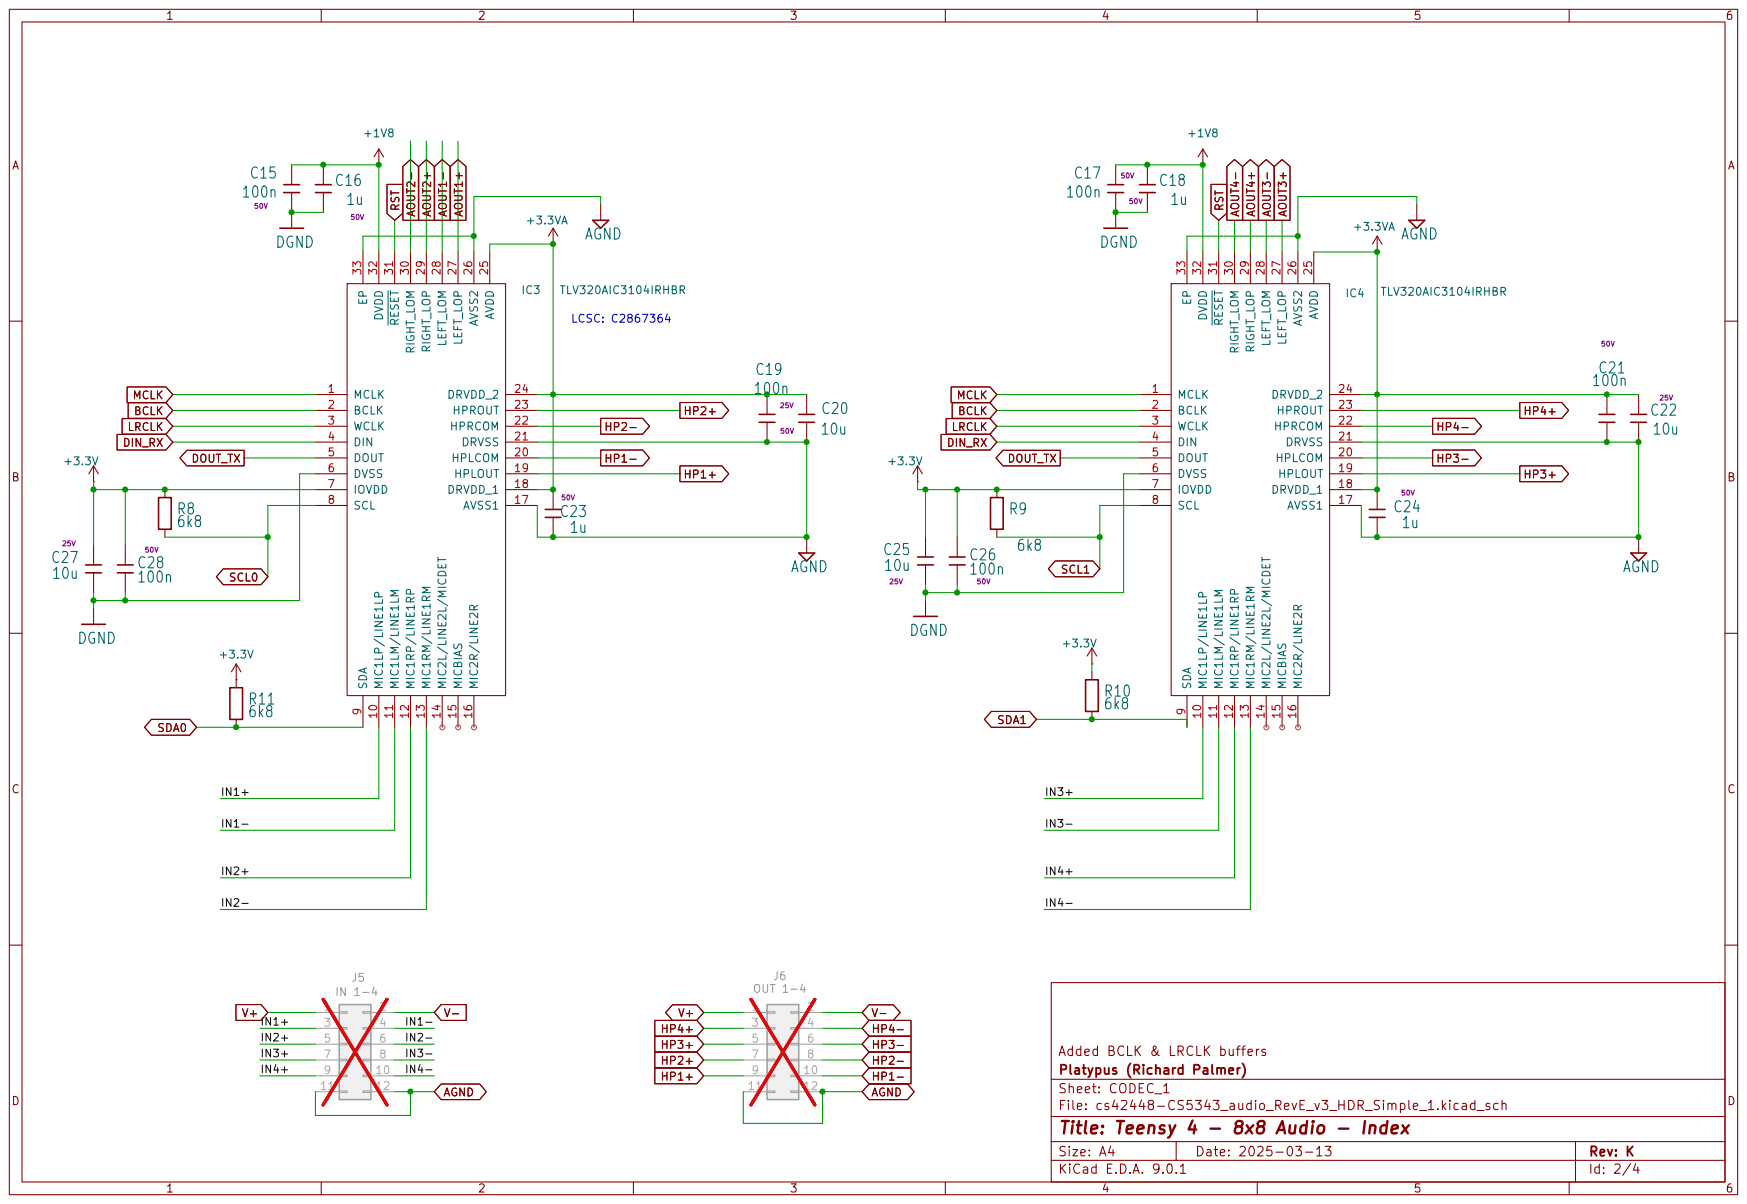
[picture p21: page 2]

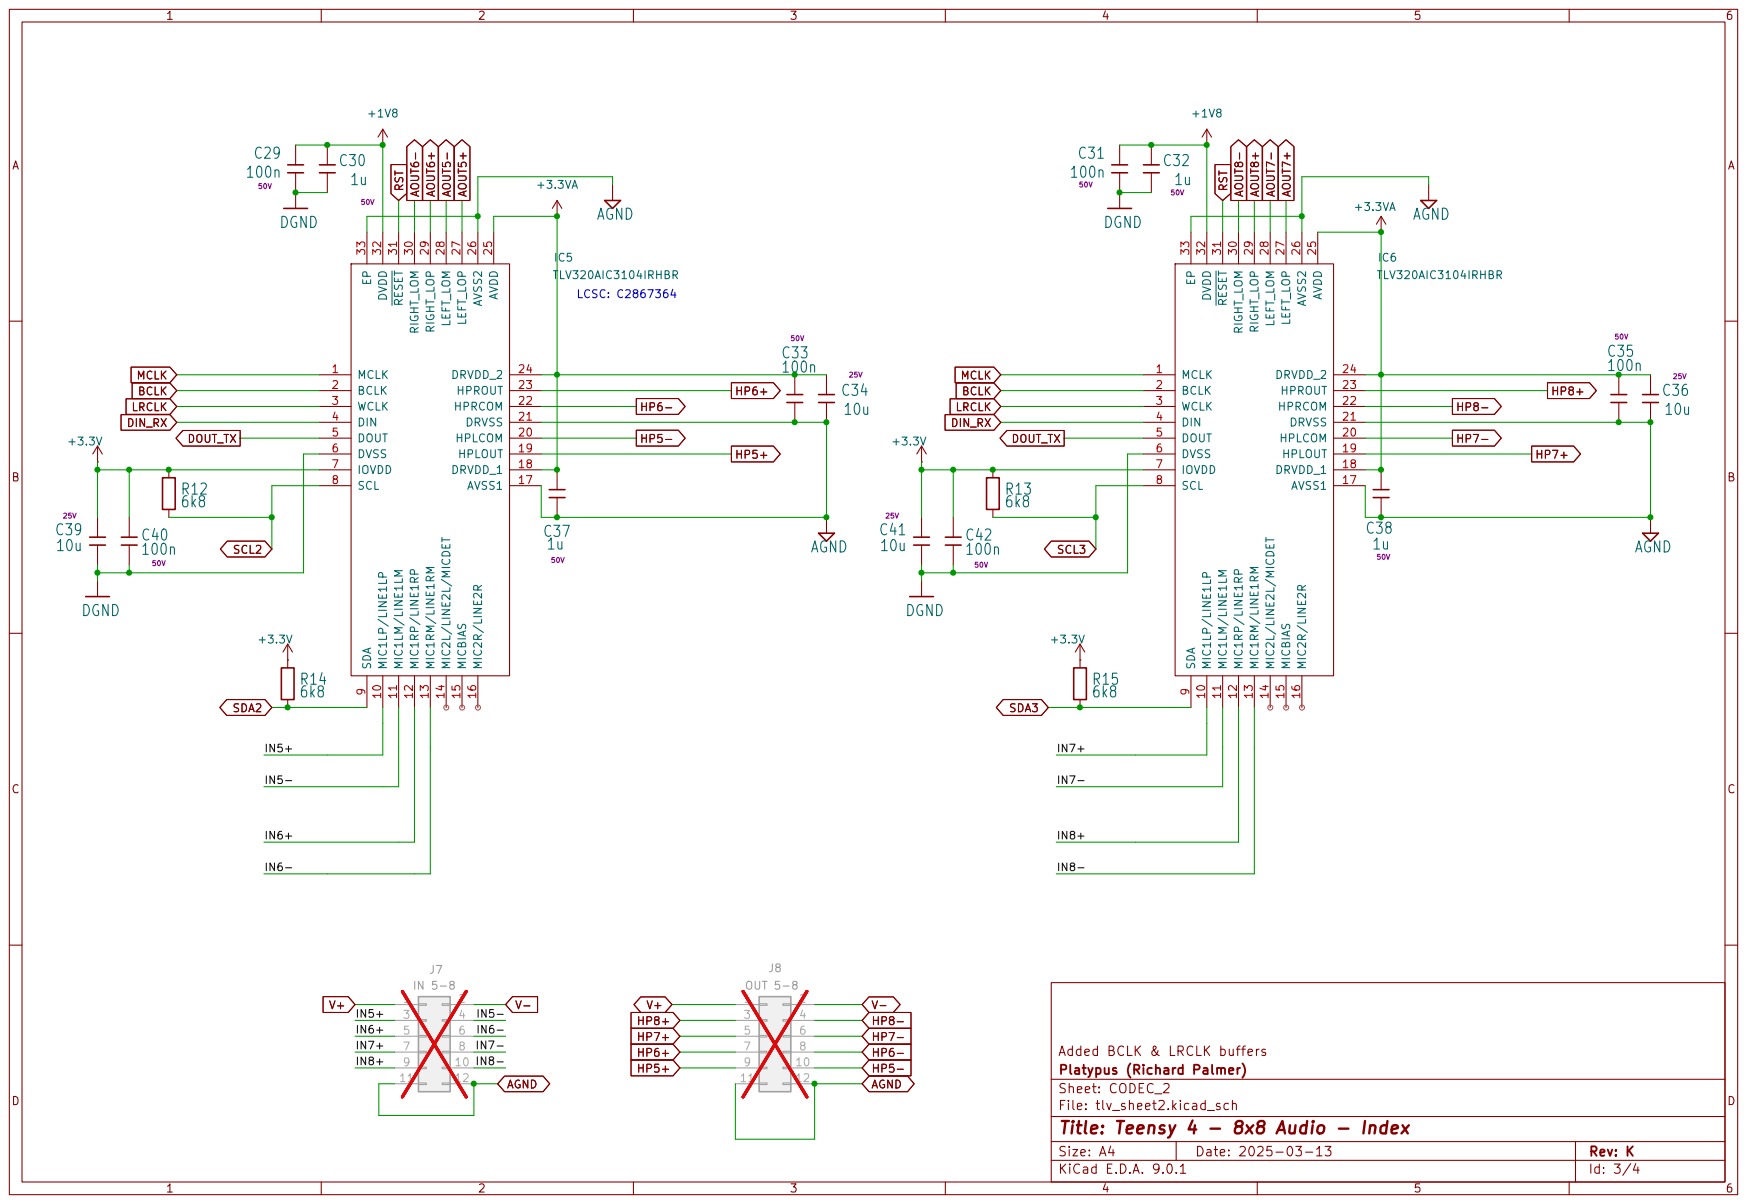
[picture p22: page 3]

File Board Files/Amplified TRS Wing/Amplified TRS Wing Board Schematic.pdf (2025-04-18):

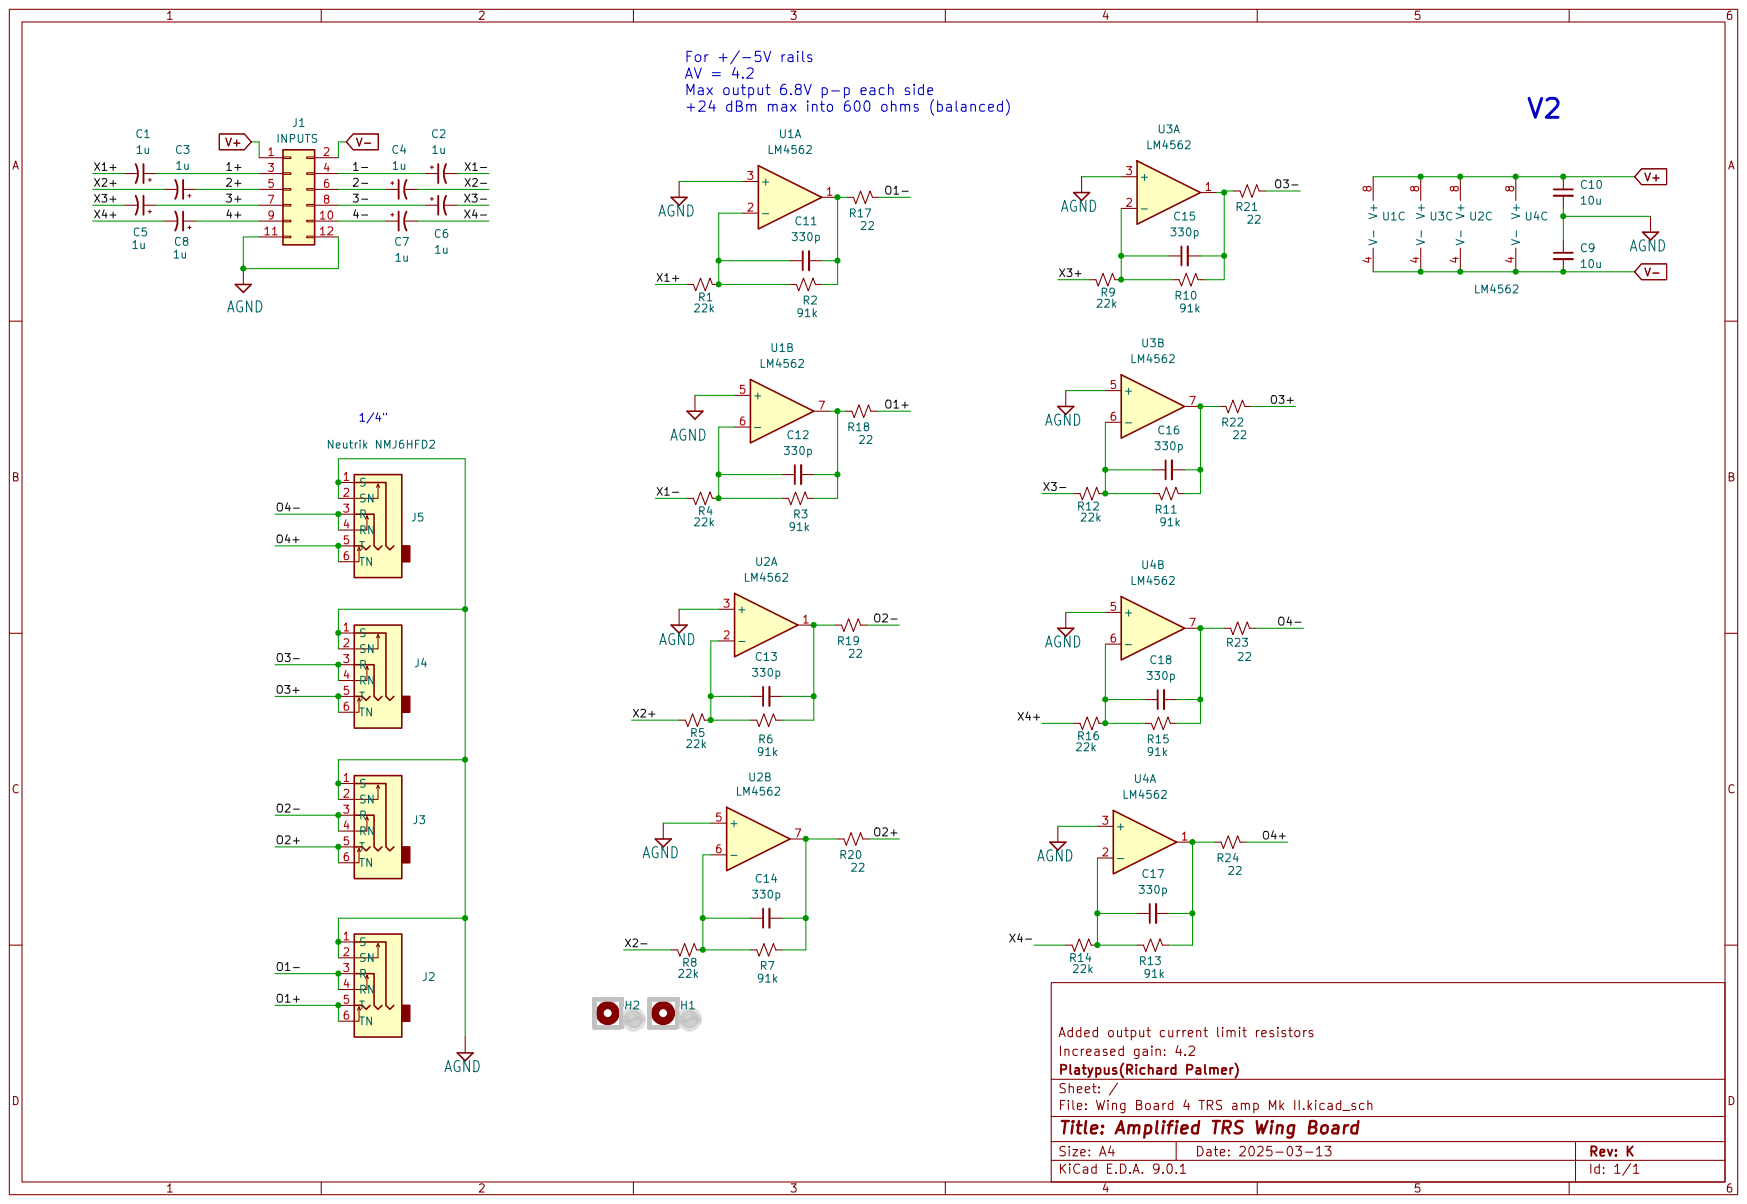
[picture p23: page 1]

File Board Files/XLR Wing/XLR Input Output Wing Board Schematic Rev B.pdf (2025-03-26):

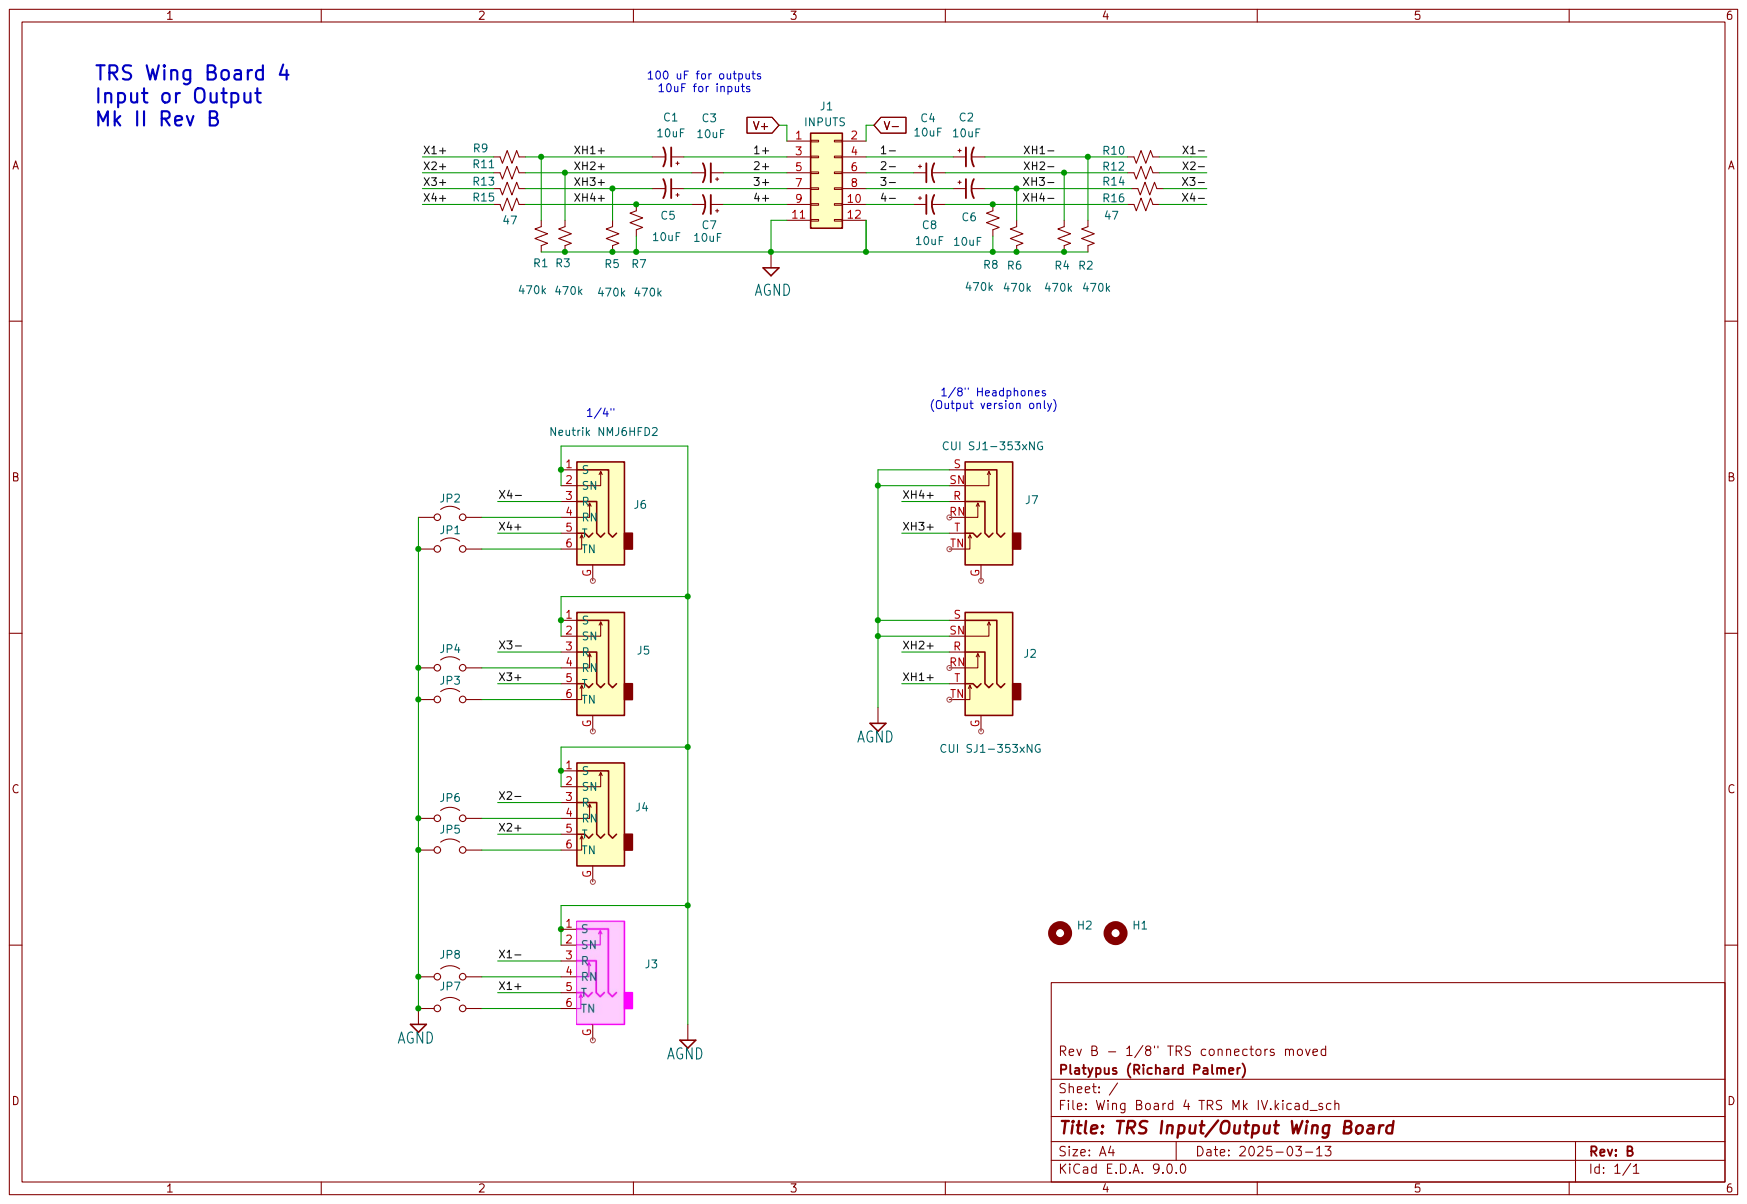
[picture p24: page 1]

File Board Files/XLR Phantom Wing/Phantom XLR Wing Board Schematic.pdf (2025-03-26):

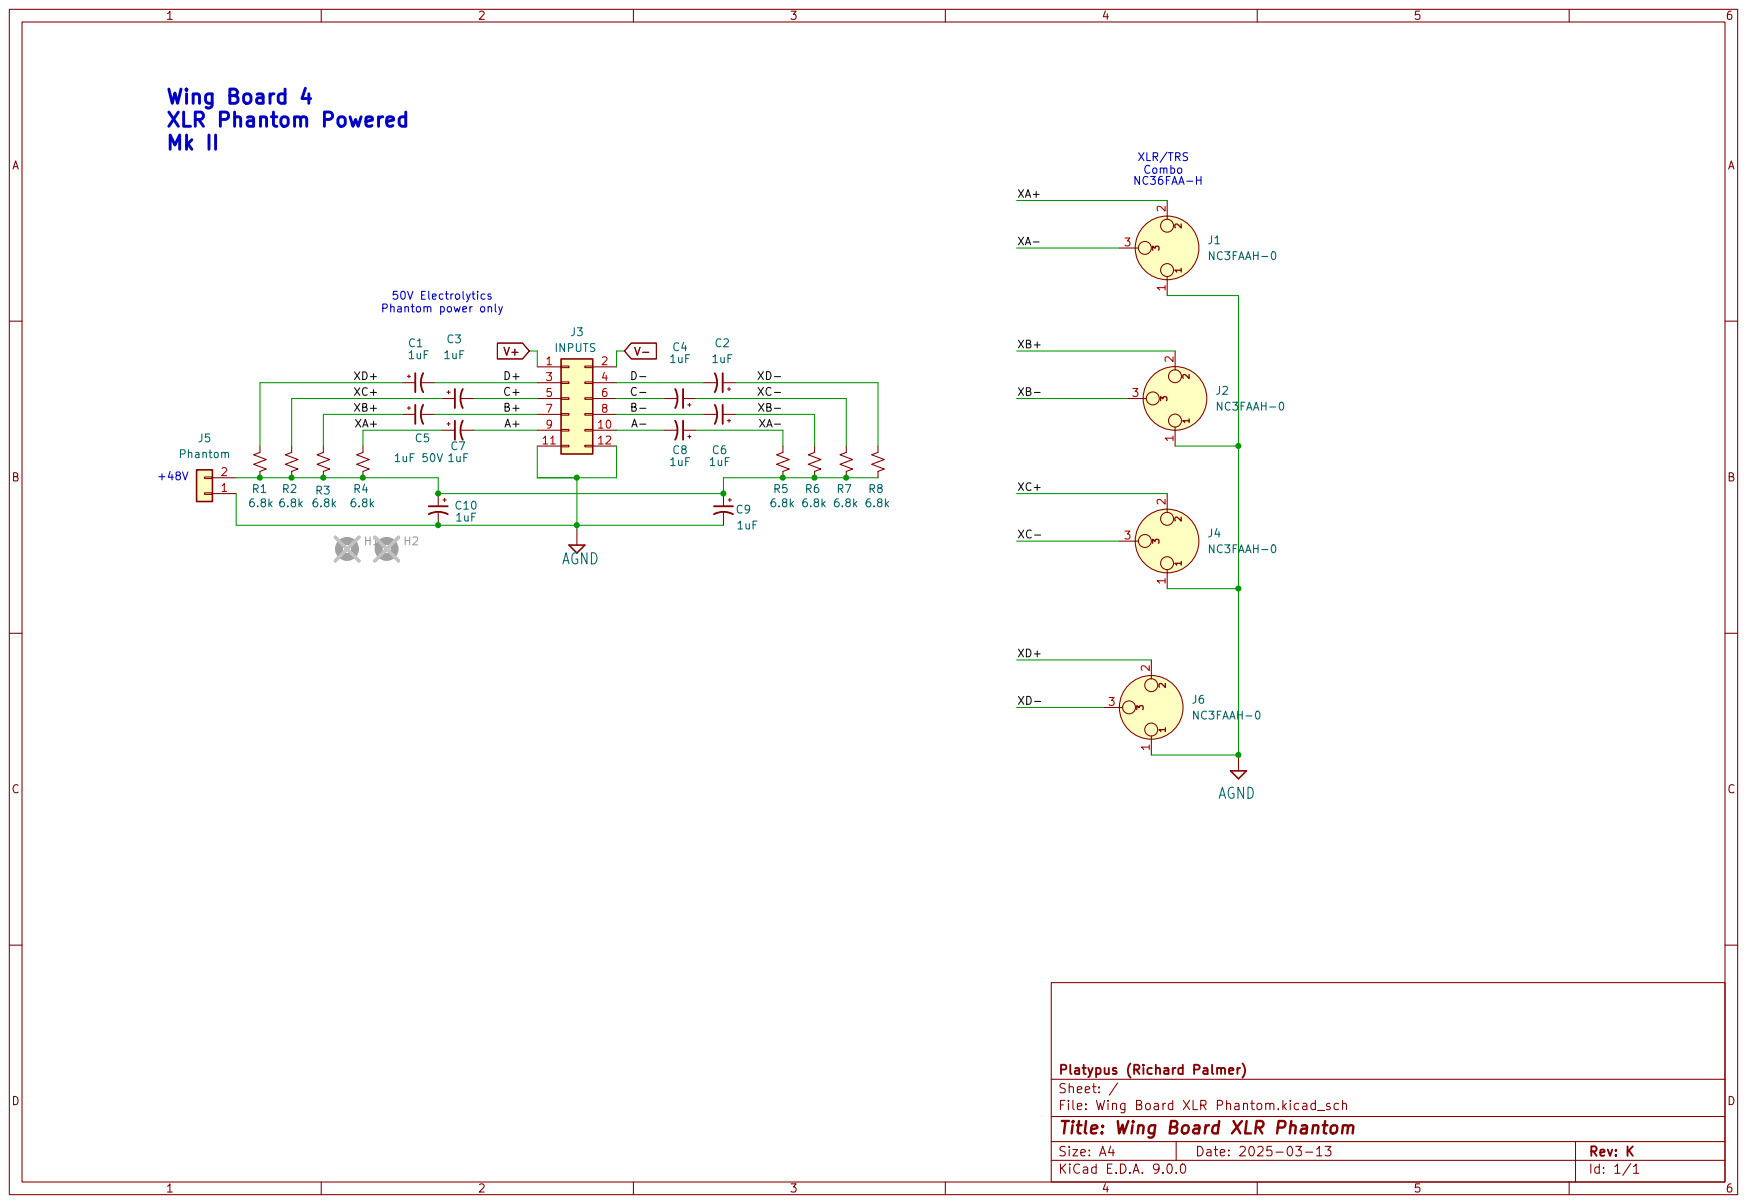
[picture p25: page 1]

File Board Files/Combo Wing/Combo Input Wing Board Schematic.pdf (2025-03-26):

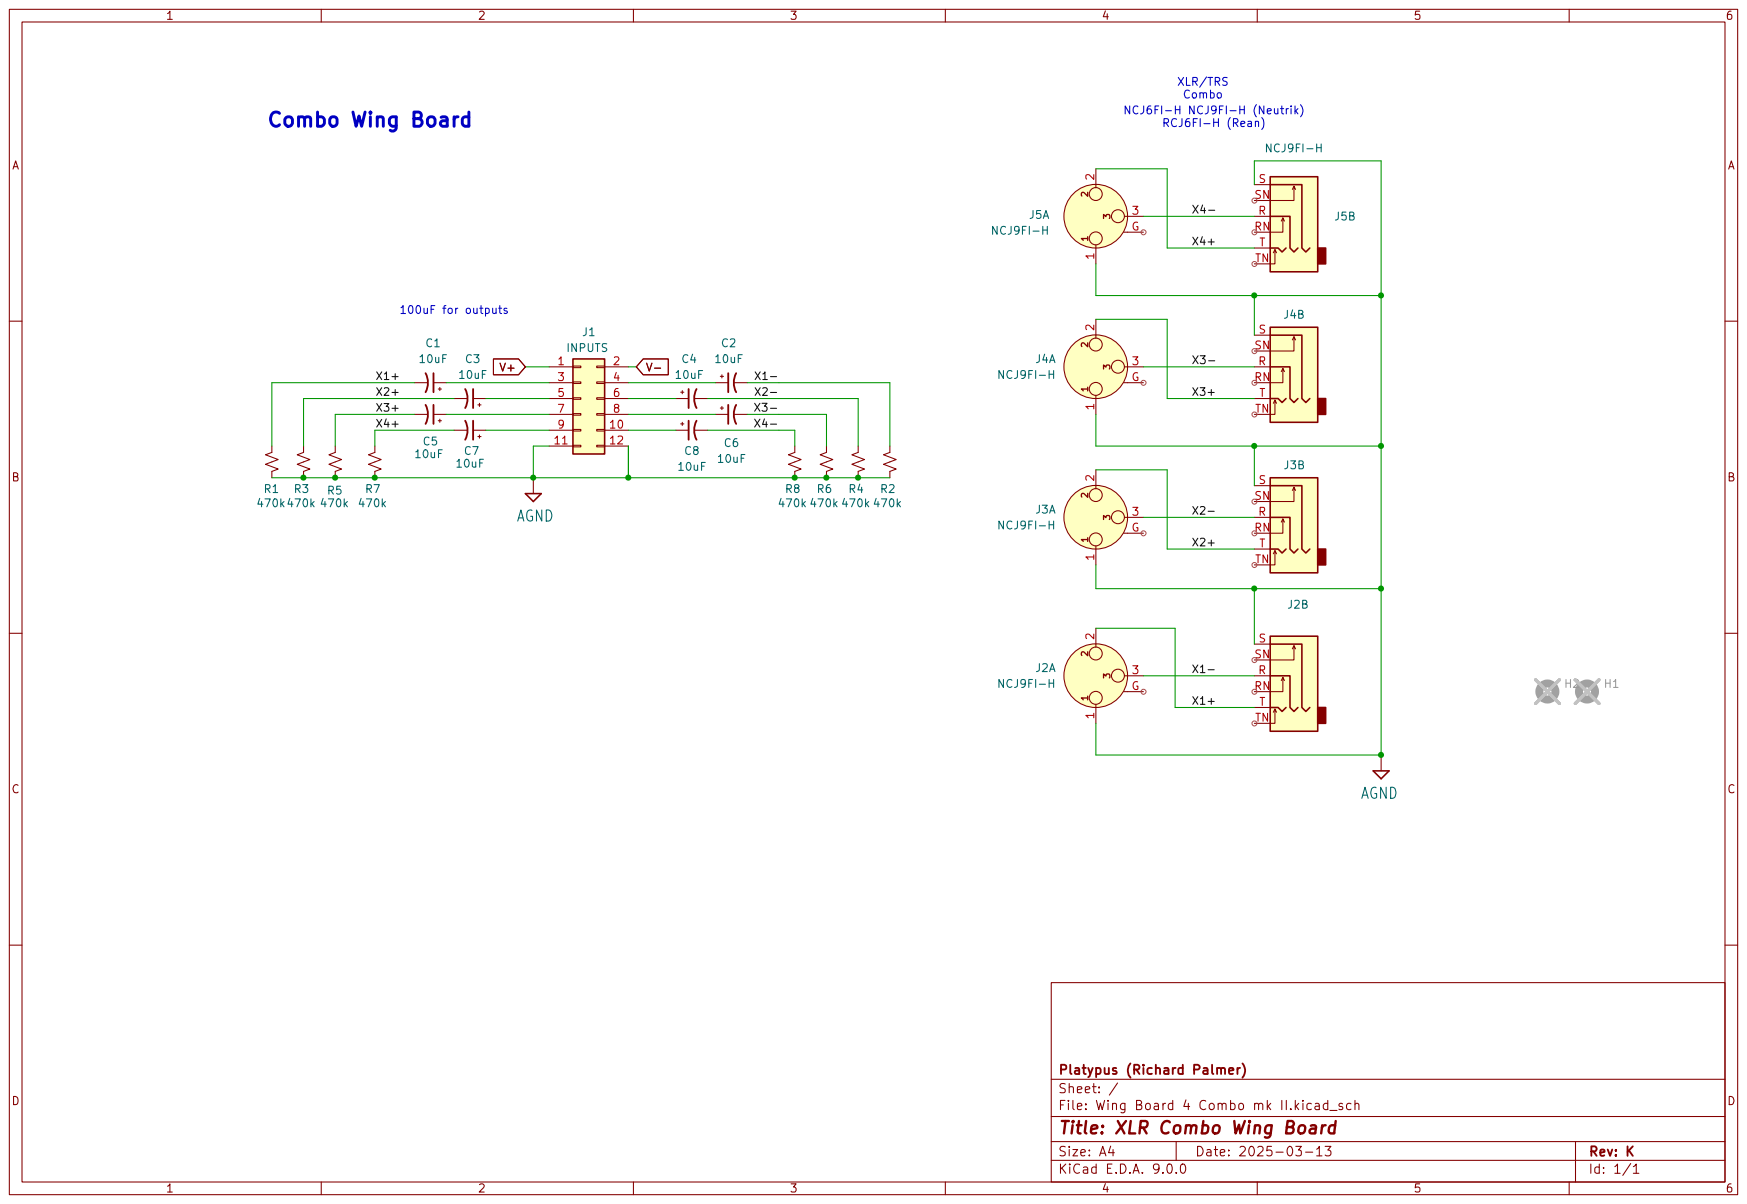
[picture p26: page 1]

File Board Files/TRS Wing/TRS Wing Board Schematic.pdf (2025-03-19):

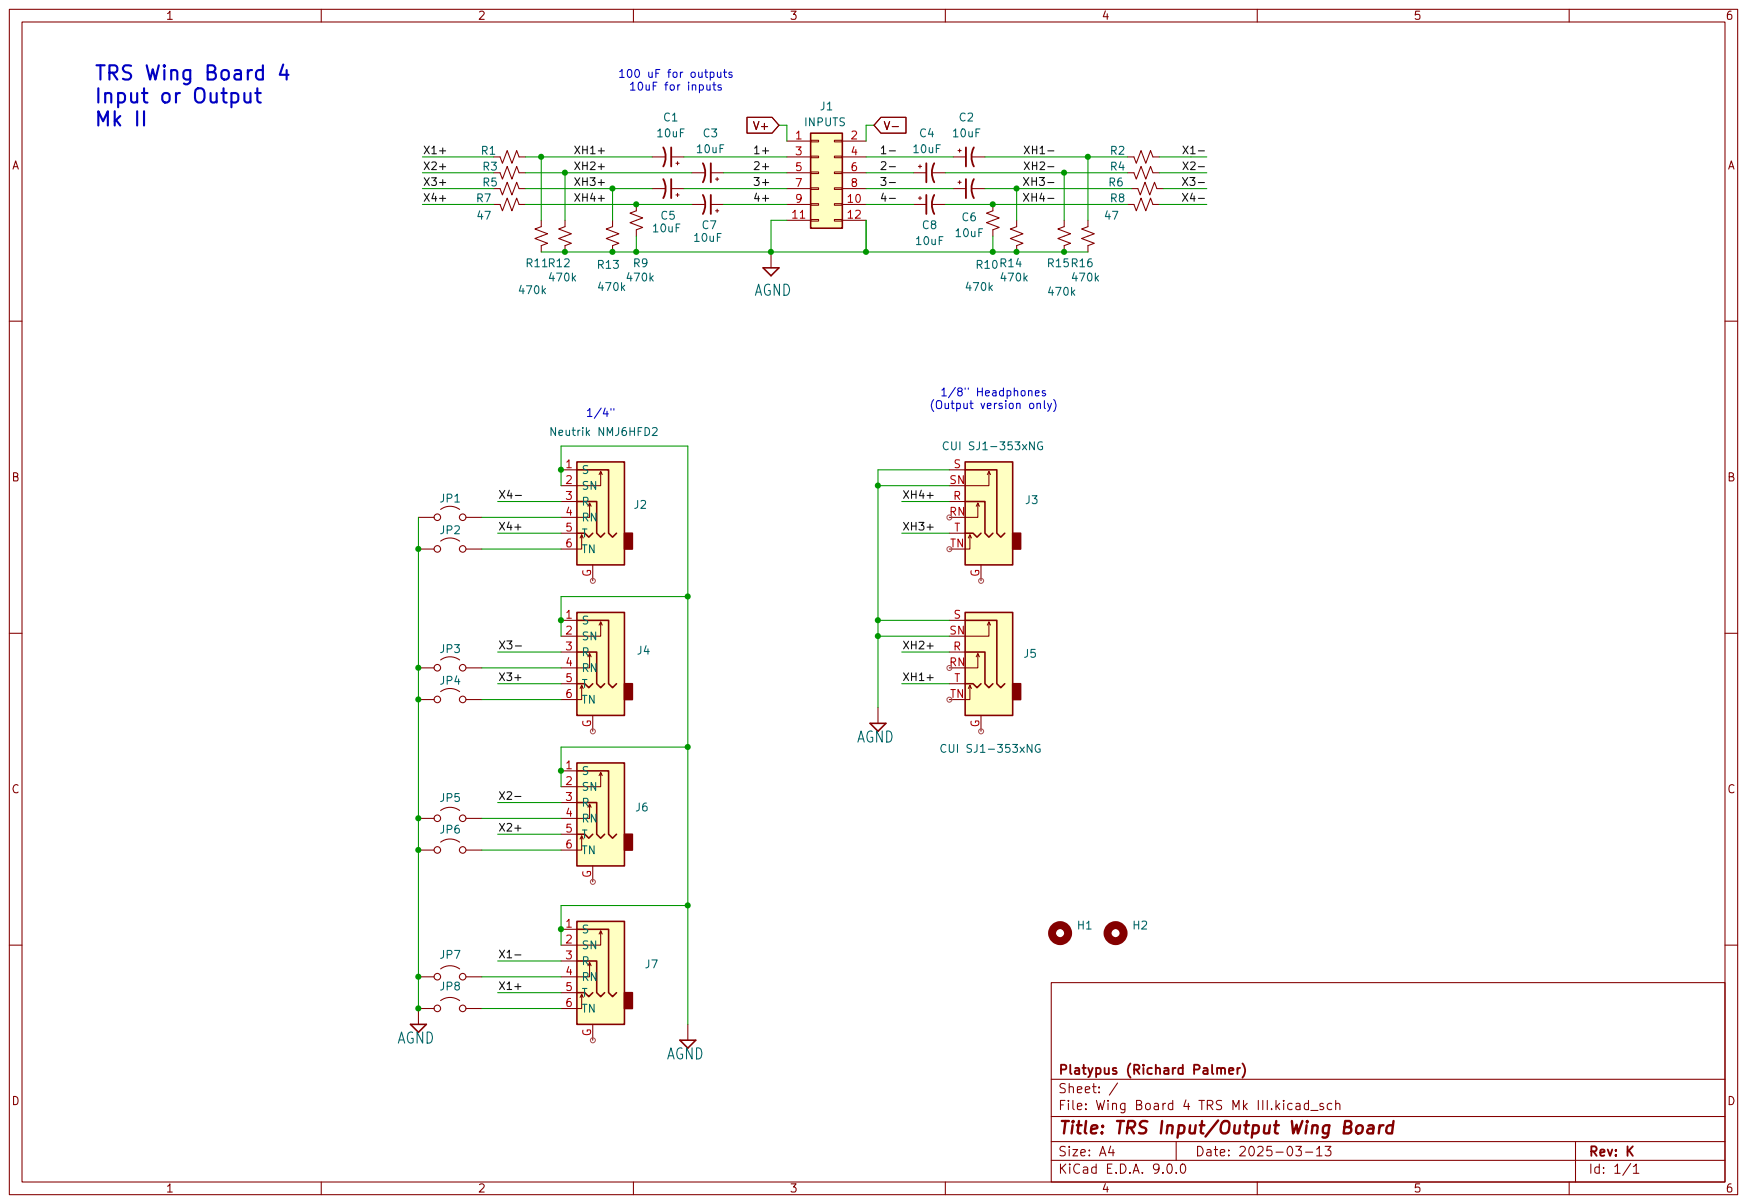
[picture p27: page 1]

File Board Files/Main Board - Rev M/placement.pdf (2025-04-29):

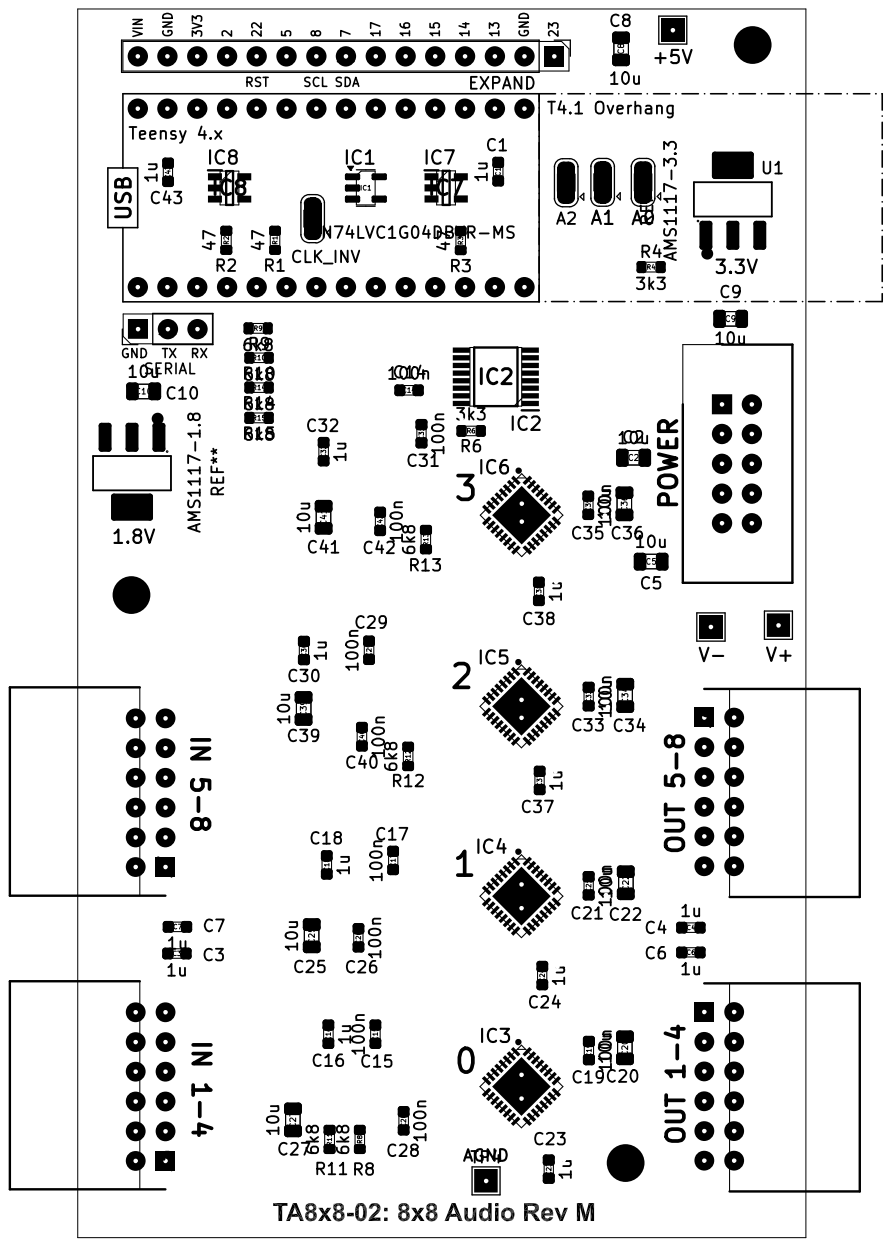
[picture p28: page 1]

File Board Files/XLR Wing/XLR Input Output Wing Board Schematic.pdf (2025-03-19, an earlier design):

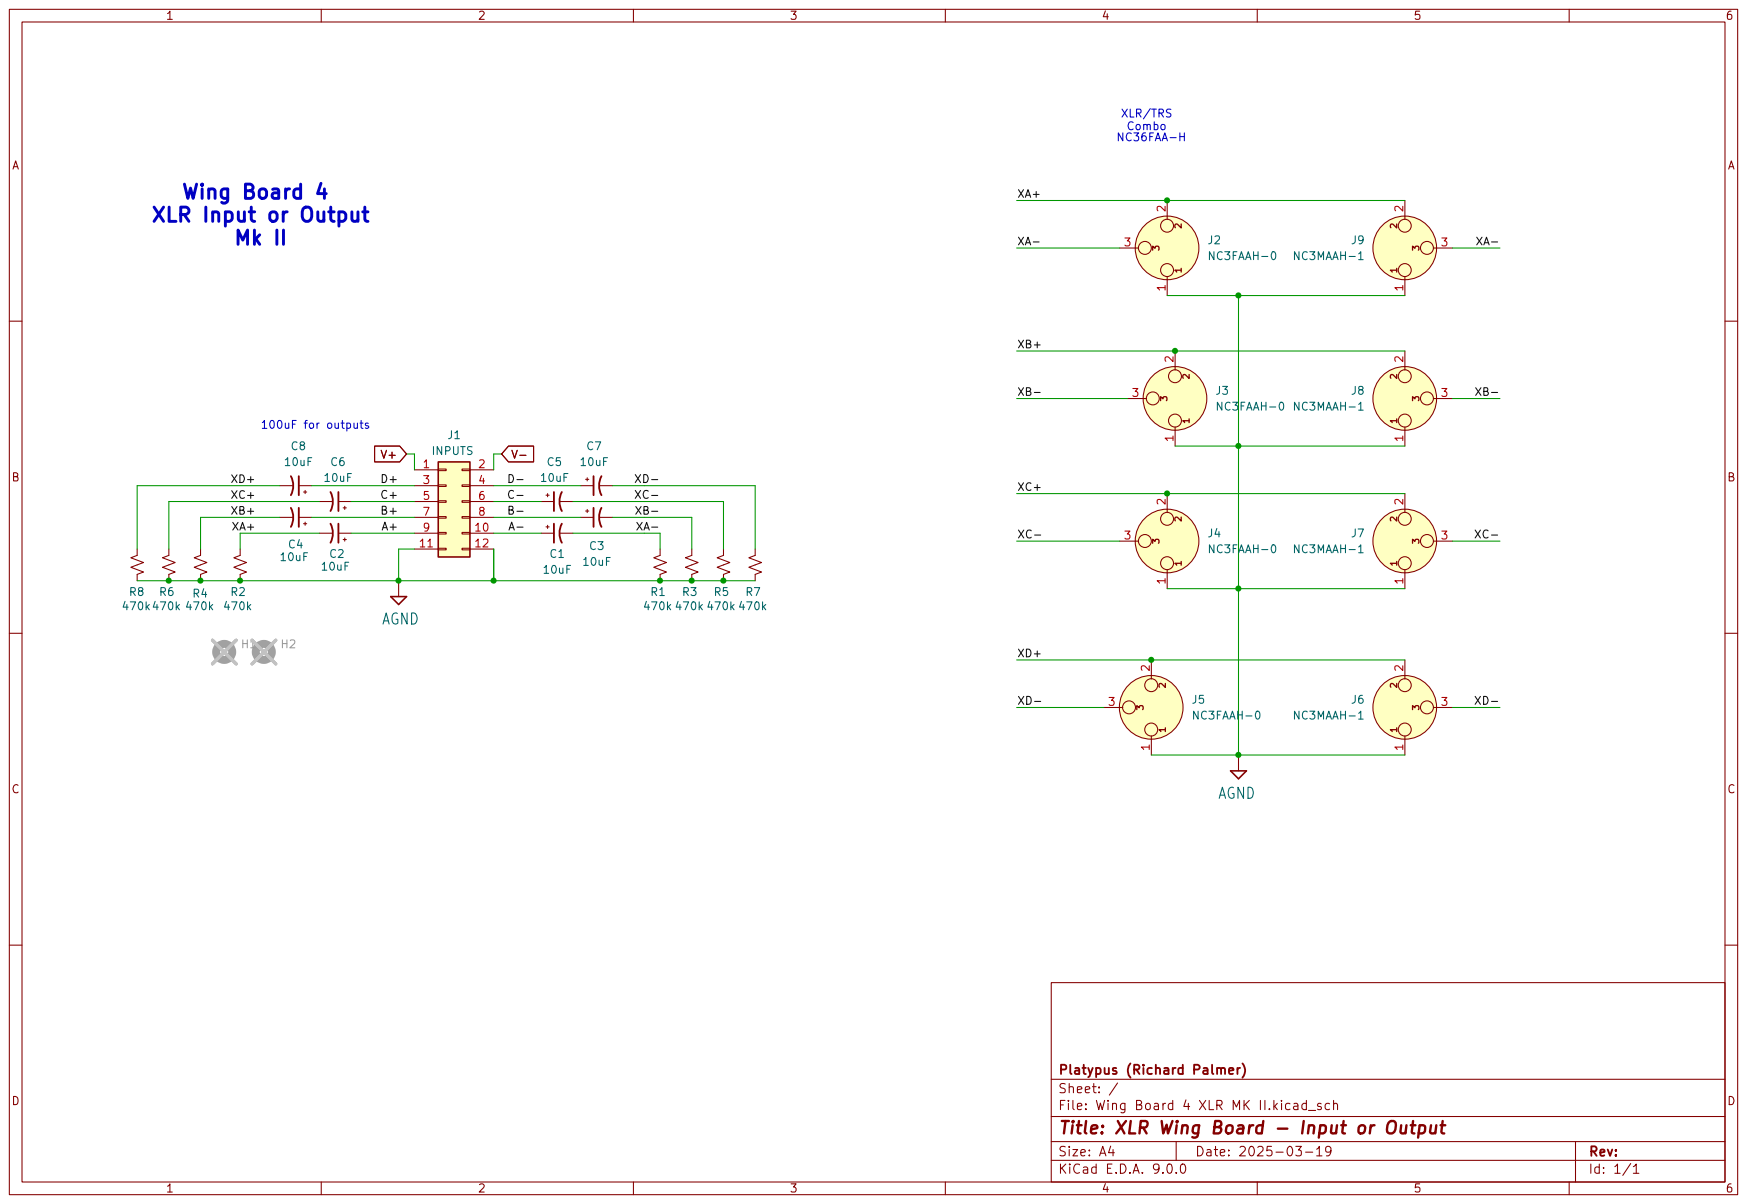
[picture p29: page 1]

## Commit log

2025-04-04 Rename 8x8 and 16x16 Teensy Audio Board.docx to Hardware notes.docx
2025-04-14 Added notes about board jumpers
2025-04-14 Add images of wing boards
2025-04-14 Moved from 'Main Board'
2025-04-15 Added extra Expansion pin for Teensy GPIO 23
    GPIO 23 used for 32x32 operation
2025-04-18 Version change - gain and current limiting
    [BOM-Wing Board 4 TRS amp Mk II.csv]
2025-04-18 Update version
    24/32 bit sample lengths
    Amplified TRS version 2
2025-04-29 Add Rev M Main board
    Board files and updated Readme.md
    [BOM-tlv320aic3104 audio rev M twist.csv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]
2025-04-29 Add Rev M main board to readme
2025-08-13 Added connector photos
2025-08-13 Added PCBA notes
2025-09-12 Added secondary schematic files
2026-03-01 3D STEP model
    [tlv320aic3104 audio rev M twist.step]
2026-03-01 KiCAD files
2026-06-01 Eurorack concept files
    [Wing Board TRS Eurorack Audio Output.kicad_pcb, Wing Board TRS Eurorack Audio Output.kicad_sch, Wing Board TRS Eurorack Control Output.kicad_pcb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]
2026-10-21 Readme and Eurorack
    Add phase reversal to readme.
    Add Eurorack Wing to boards
